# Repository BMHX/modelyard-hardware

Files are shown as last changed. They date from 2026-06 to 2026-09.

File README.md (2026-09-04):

<h1 align="center">Forge 60</h1>

<p align="center">
  <strong>Open-hardware 60 W / 10,000 lm DIY flashlight kit with USB-C power, active cooling, and full manufacturing files.</strong>
</p>

<p align="center">
  
  
  
  
</p>

<p align="center">
  
  
  
</p>

<p align="center">
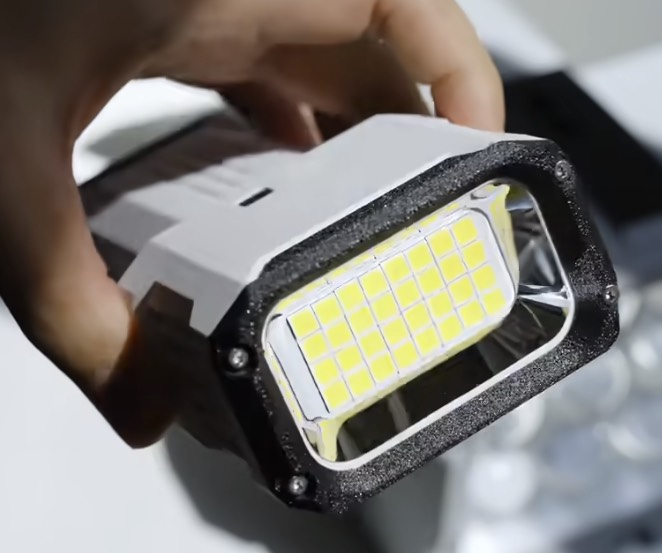
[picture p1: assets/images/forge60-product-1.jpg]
Forge 60 product photo
  
</p>

Forge 60 is a reproducible open-hardware flashlight platform built around a constant 60 W / 10,000 lm output mode, a high-current driver board, a 5050 LED board, active cooling, and a USB-C charge/discharge power path. The repository includes fabrication files, assembly data, schematics, and editable EasyEDA Pro source files so builders can manufacture, inspect, modify, and assemble the project.

## Quick Links

| Action | Link |
| --- | --- |
| YouTube Watch demo | [YouTube video](https://www.youtube.com/watch?v=xSCZzmICGlw) |
| Shopify Buy kit | [ModelYard Forge 60 kit](https://modelyard.cc/products/forge-60) |
| Discord Join community | [Discord invite](https://discord.gg/PhqGwtabfa) |
| GitHub Download release | [GitHub Releases](https://github.com/BMHX/modelyard-hardware/releases) |
| Hardware Download hardware files | [Hardware Downloads](#hardware-downloads) |
| Firmware Download firmware | [Forge 60 OS v1.2 HEX](forge60-hardware-release/firmware/forge60-os-v1.2.hex) |
| Mechanical model Download mechanical model | [Forge 60 v10 3MF](forge60-hardware-release/mechanical/forge60-v10.3mf) |
| Accessory package Download accessory files | [Accessory Package](#accessory-package) |
| Source project Edit source project | [EasyEDA Pro source](forge60-hardware-release/source/forge60-easyeda-pro-source.epro2) |

## At a Glance

| Item | Value |
| --- | --- |
| Output | 60 W / about 10,000 lm |
| USB-C power | About 45 W charging / discharging |
| Battery architecture | 2S 21700 lithium battery pack |
| Cooling | 30 x 30 x 50 mm heatsink + 3010 fan |
| Recommended hardware files | Mainboard v2 + 5050 LED board |
| Mainboard thickness | 1.0 mm |
| LED board thickness | 1.6 mm |
| Firmware | Forge 60 OS v1.2 HEX |
| Mechanical model | Forge 60 v10 3MF |
| Source format | EasyEDA Pro `.epro2` |
| License | CERN-OHL-P-2.0 |

## Important Notes

- **Recommended board:** use `mainboard-v2`. Older mainboard revisions are not recommended for new builds.
- **PCB thickness matters:** order the mainboard at **1.0 mm** and the LED board at **1.6 mm**.
- **LED part:** the 5050 LED board is intended for 6 V 5050 emitters. Current kits use Seoul Semiconductor `STW0L8PA`, 5700 K, around CRI 70. The LED BOM does not use an LCSC part number.
- **KiCad is not included yet:** editable source is currently provided as an EasyEDA Pro project.
- **High-power safety:** this project uses high-current lithium cells and a high-power LED. Validate wiring, polarity, thermal path, and firmware before sustained operation.
- **Battery shipping:** if you ship kits with cells, use a logistics channel that supports lithium batteries.

## Contents

- [Demo](#demo)
- [Kit Availability](#kit-availability)
- [Performance](#performance)
- [Hardware Downloads](#hardware-downloads)
- [Manufacturing Notes](#manufacturing-notes)
- [Firmware and Mechanical Files](#firmware-and-mechanical-files)
- [Accessory Package](#accessory-package)
- [Source Project](#source-project)
- [PCB and Schematic Preview](#pcb-and-schematic-preview)
- [BOM Overview](#bom-overview)
- [Build Flow](#build-flow)
- [Firmware Flashing](#firmware-flashing)
- [Assembly Notes](#assembly-notes)
- [Safety and Disclaimer](#safety-and-disclaimer)
- [Repository Layout](#repository-layout)
- [License](#license)

## Demo

Forge 60 demo video (https://www.youtube.com/watch?v=xSCZzmICGlw)

Watch the demo: [https://www.youtube.com/watch?v=xSCZzmICGlw](https://www.youtube.com/watch?v=xSCZzmICGlw)

## Kit Availability

This repository contains the open hardware files for builders who want to manufacture or modify the project themselves. A ready-to-build kit is available separately:



Direct link: [https://modelyard.cc/products/forge-60](https://modelyard.cc/products/forge-60)

## Performance

| Mode | Runtime |
| --- | --- |
| 60 W | About 27 minutes |
| 30 W | About 54 minutes |
| 3 W | About 8 hours |

These are reference values from the project build. Final performance depends on LED bin, cell condition, protection board, wiring resistance, cooling quality, firmware, and assembly.

## Hardware Downloads

Gerber files are for PCB fabrication. BOM files are for sourcing. Pick-and-place files are for SMT assembly. Schematic and PCB preview files are provided for review.

| Board | Gerber | BOM | Pick and Place | Schematic | PCB Preview |
| --- | --- | --- | --- | --- | --- |
| Mainboard v2 | [ZIP](forge60-hardware-release/mainboard-v2/mainboard-v2-gerber.zip) | [XLSX](forge60-hardware-release/mainboard-v2/mainboard-v2-bom.xlsx) / [CSV](forge60-hardware-release/mainboard-v2/mainboard-v2-bom.csv) | [XLSX](forge60-hardware-release/mainboard-v2/mainboard-v2-pick-and-place.xlsx) / [CSV](forge60-hardware-release/mainboard-v2/mainboard-v2-pick-and-place.csv) | [PDF](forge60-hardware-release/mainboard-v2/mainboard-v2-schematic.pdf) | [PDF](forge60-hardware-release/mainboard-v2/mainboard-v2-pcb-preview.pdf) |
| 5050 LED Board | [ZIP](forge60-hardware-release/led-board-5050/led-board-5050-gerber.zip) | [XLSX](forge60-hardware-release/led-board-5050/led-board-5050-bom.xlsx) / [CSV](forge60-hardware-release/led-board-5050/led-board-5050-bom.csv) | [XLSX](forge60-hardware-release/led-board-5050/led-board-5050-pick-and-place.xlsx) / [CSV](forge60-hardware-release/led-board-5050/led-board-5050-pick-and-place.csv) | [PDF](forge60-hardware-release/led-board-5050/led-board-5050-schematic.pdf) | [PDF](forge60-hardware-release/led-board-5050/led-board-5050-pcb-preview.pdf) |

## Manufacturing Notes

- Mainboard v2: order as **1.0 mm** PCB.
- 5050 LED board: order as **1.6 mm** PCB.
- Use the Gerber zip, BOM, and pick-and-place files from the same board folder.
- The BOM files are the source of truth for electronic components; verify substitutes before assembly.
- If outsourcing SMT, provide the manufacturer with Gerber, BOM, and pick-and-place files together.

## Firmware and Mechanical Files

| File | Link | Use |
| --- | --- | --- |
| Forge 60 OS v1.2 firmware | [forge60-os-v1.2.hex](forge60-hardware-release/firmware/forge60-os-v1.2.hex) | Flash the PY32F003xx6 mainboard MCU |
| Forge 60 v10 mechanical model | [forge60-v10.3mf](forge60-hardware-release/mechanical/forge60-v10.3mf) | 3D-printable mechanical shell/model package |

## Accessory Package

Additional Forge-series accessory files, 3D models, firmware files, stencil files, and source model files are provided at the repository root.

| Folder | Contents |
| --- | --- |
| [Forge60Mecha_Edition](Forge60Mecha_Edition) | Forge 60 Mecha Edition Fusion 360 source, STL package, 3MF package, extended handle STL, and add-on 3MF |
| [Forge65 3D_Files](Forge65%203D_Files) | Forge 65 3MF files, STL package, extended handle 3MF, and 8-cell package |
| [Forge60 65Stencil](Forge60%2065Stencil) | Forge 60 v2 mainboard stencil DXF |
| [Forge200 3D_Models](Forge200%203D_Models) | Forge 200 Fusion 360 source files, STL files, and 3MF files |
| [Forgeos Firmware](Forgeos%20Firmware) | Forge OS firmware HEX files for Forge 60, Forge 65/66, and Forge 201, plus user guide images |
| [Forge500](Forge500) | Forge 500 UF2 firmware files, print files, Fusion 360 source, add-ons, and offline replication document |
| [Forge201 3D_Files](Forge201%203D_Files) | Forge 201 STL package, Fusion 360 source package, 3MF file, and reflective film mold STL |

## Source Project

| Format | Download |
| --- | --- |
| EasyEDA Pro source | [forge60-easyeda-pro-source.epro2](forge60-hardware-release/source/forge60-easyeda-pro-source.epro2) |

The editable project is currently provided in EasyEDA Pro format. KiCad files are not included in this release.

## PCB and Schematic Preview

### PCB Preview

| Mainboard v2 | 5050 LED Board |
| --- | --- |
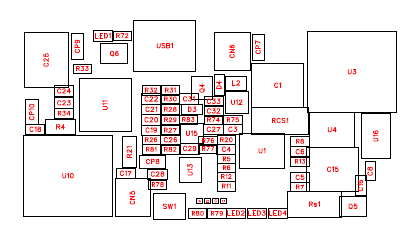
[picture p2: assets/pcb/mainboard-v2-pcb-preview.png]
Mainboard v2 PCB preview
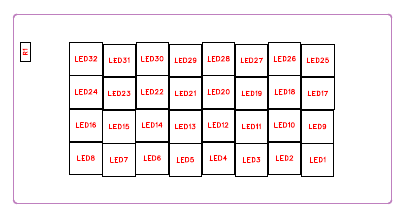
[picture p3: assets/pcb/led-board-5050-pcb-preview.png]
5050 LED board PCB preview
|  |  |

### Schematic Preview

| Mainboard v2 | 5050 LED Board |
| --- | --- |
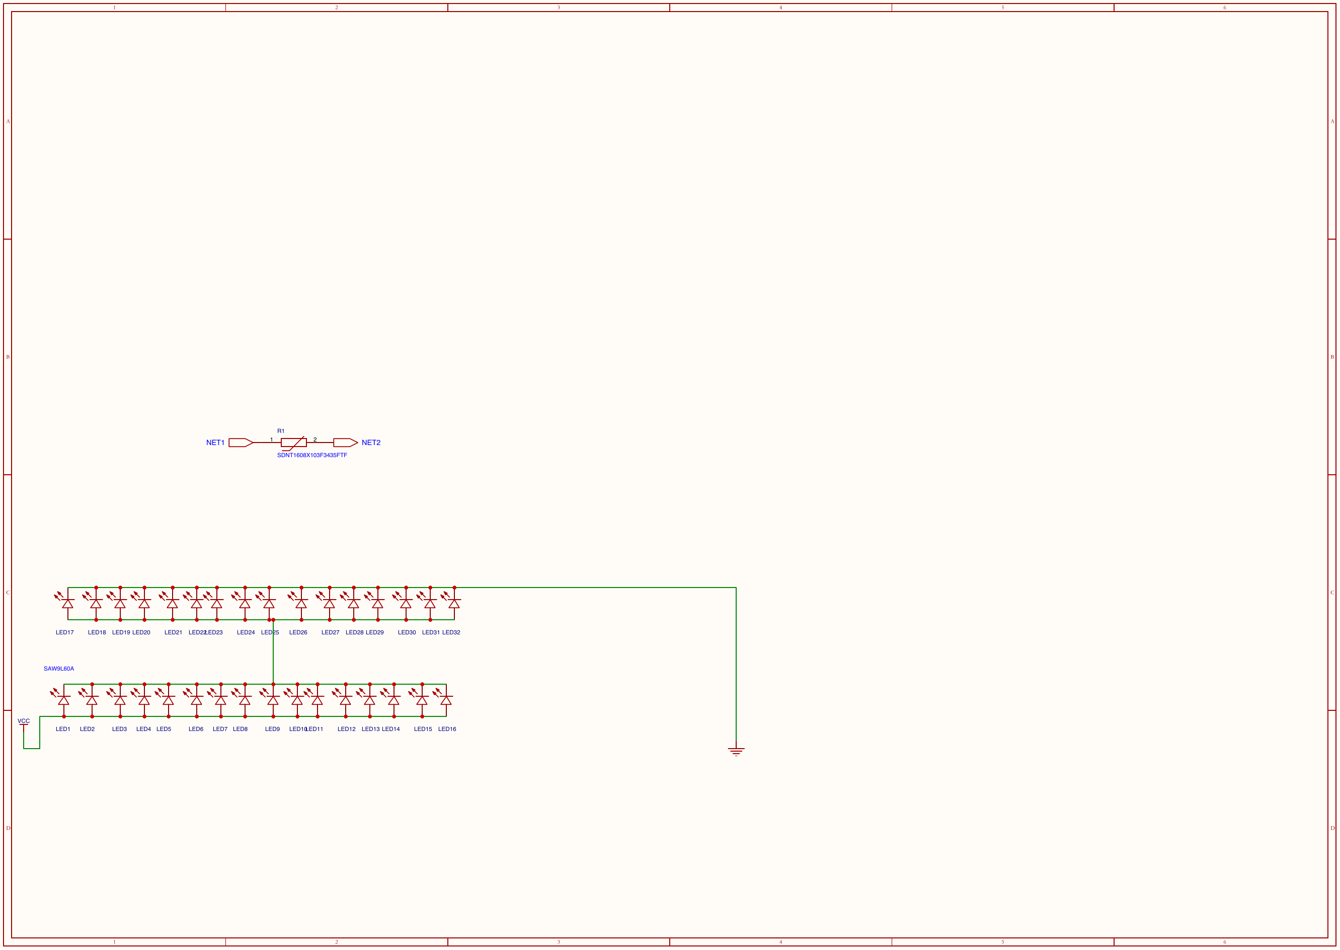
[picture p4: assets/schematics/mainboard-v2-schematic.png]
Mainboard v2 schematic
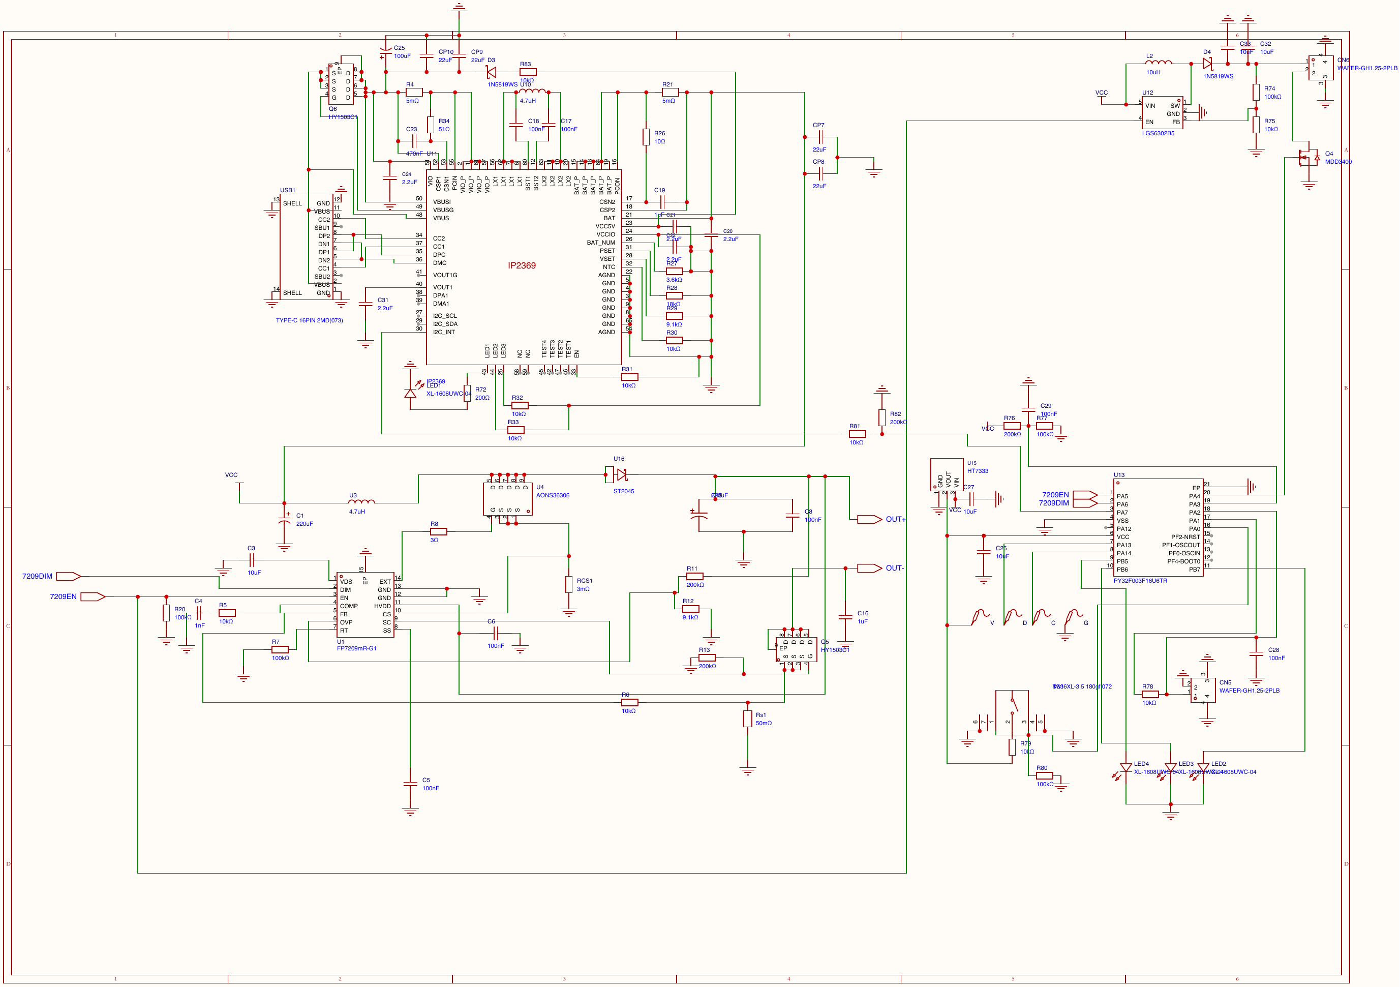
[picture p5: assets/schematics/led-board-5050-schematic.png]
5050 LED board schematic
|  |  |

## BOM Overview

The full BOM is provided in the hardware download table. Major parts include:

- IP2369 charge/discharge controller
- FP7209 LED driver controller
- PY32F003 series MCU
- Seoul Semiconductor STW0L8PA 6 V 5050 LEDs, 5700 K, around CRI 70
- 2S protection board, 13 A class recommended
- High-drain 21700 cells, such as JP40 / 40PL / 45D class cells
- 30 x 30 x 50 mm heatsink
- 3010 cooling fan
- 74 mm protective glass
- XT30 male/female connectors
- GH1.25 2P cables
- 20 AWG and 16 AWG flexible silicone wires
- M1.4 and M1.7 heat-set inserts
- Reflective film, thermal tape, thermal grease, shock-absorbing foam, and high-temperature tape

## Build Flow

1. Review the schematic PDFs and PCB previews.
2. Order the mainboard and LED board using the Gerber files and thickness notes.
3. Source components from the BOM.
4. Use pick-and-place files for SMT assembly where applicable.
5. Print or prepare the mechanical parts and cooling stack.
6. Flash the mainboard firmware.
7. Assemble wiring, LED board, fan, battery pack, and enclosure.
8. Perform current-limited first power-on testing and monitor temperature.

## Required Tools

- 3D printer
- Spot welder
- Hot plate or hot air station
- Soldering iron
- PWLINK2 LITE programmer
- 1.25 mm programming probe
- Glass cutter, if cutting the protective glass manually
- H1.3 / H1.5 hex drivers

## Firmware Flashing

Use PWLINK2 LITE and select the PY32F003xx6 series target in the programming software. Pay close attention to the V and G pads on the mainboard. Reversed programming probe wiring can damage the board.

| Select MCU | Add firmware | Apply firmware |
| --- | --- | --- |
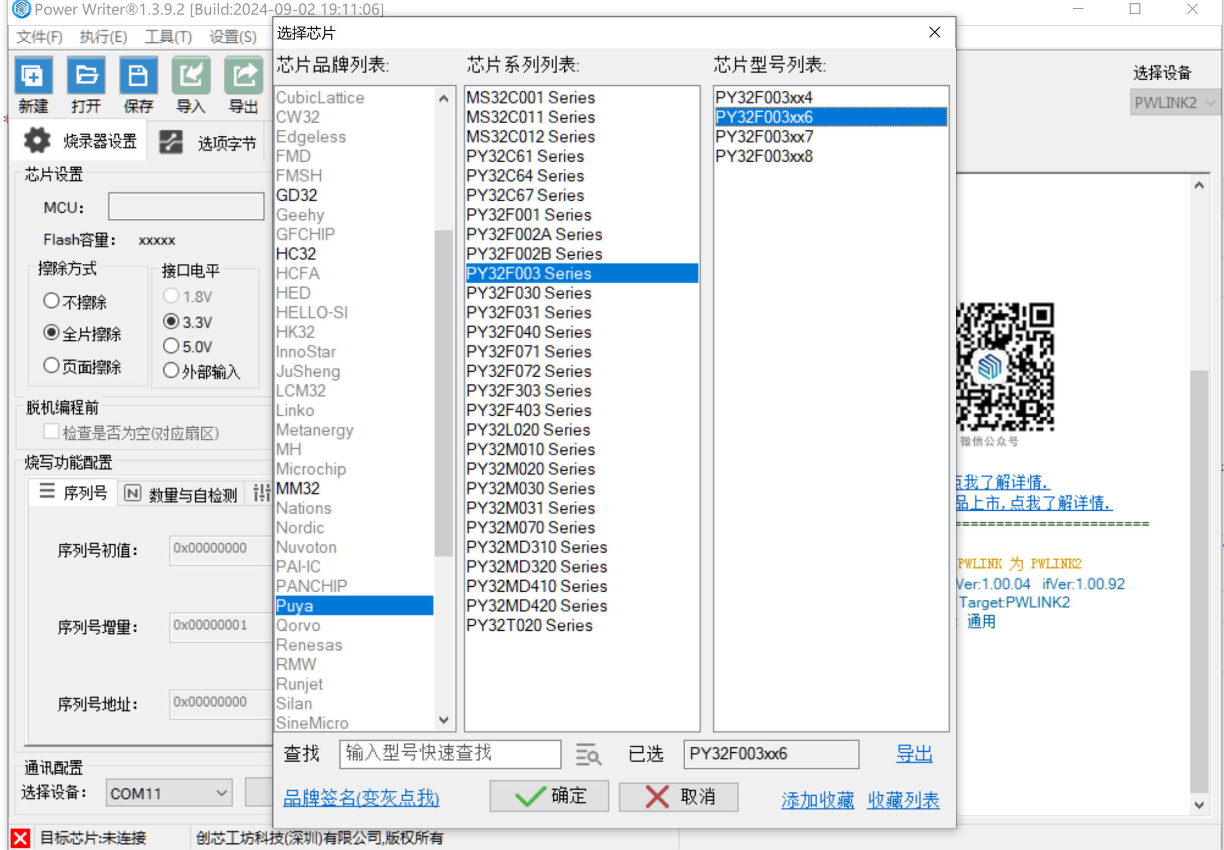
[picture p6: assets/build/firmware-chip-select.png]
Select chip
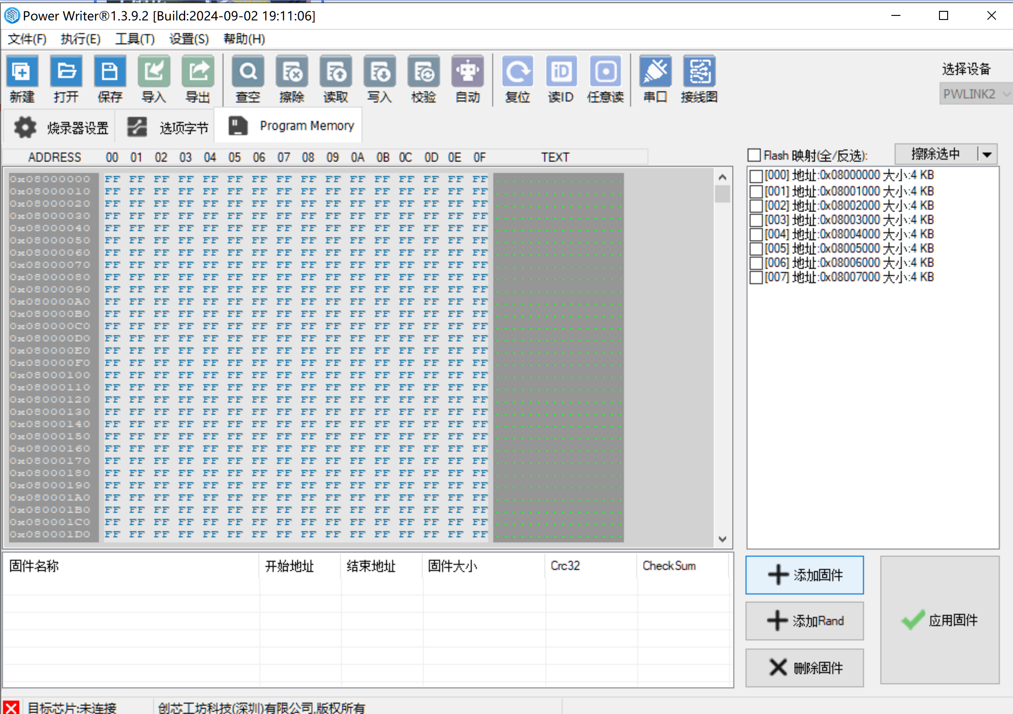
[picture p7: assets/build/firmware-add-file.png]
Add firmware
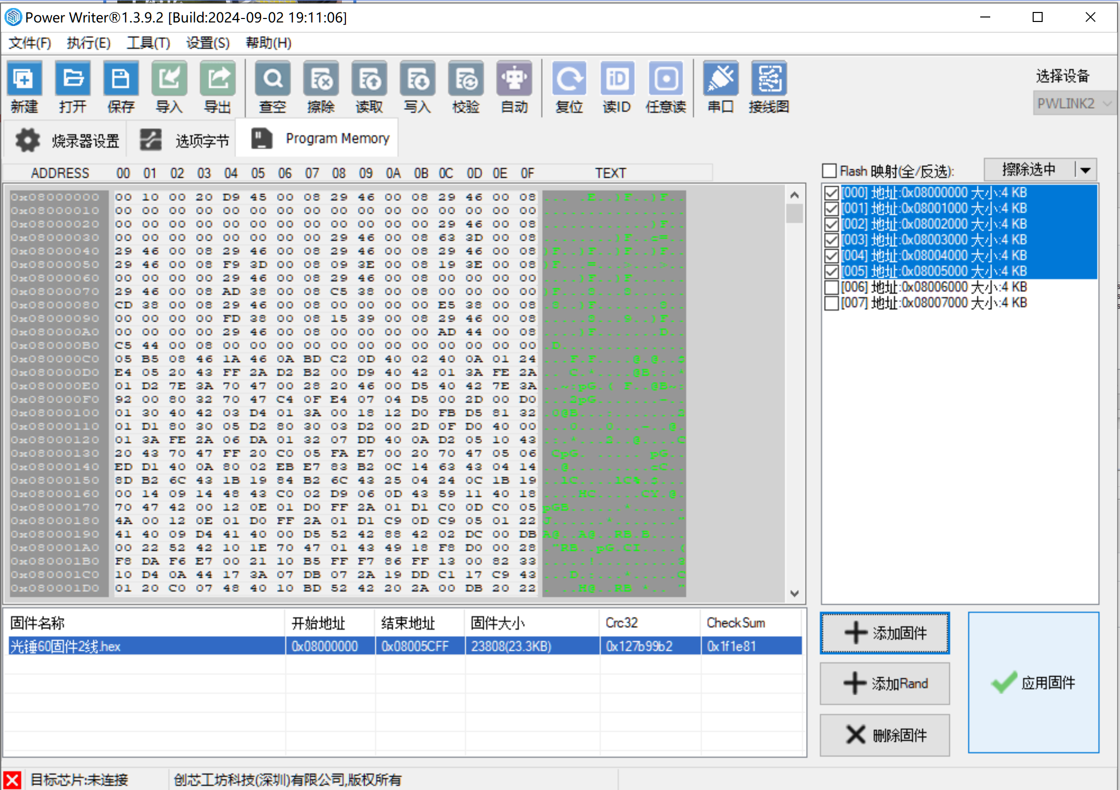
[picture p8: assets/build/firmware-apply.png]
Apply firmware
|  |  |  |

| Probe wiring | Mainboard pads | Program complete |
| --- | --- | --- |
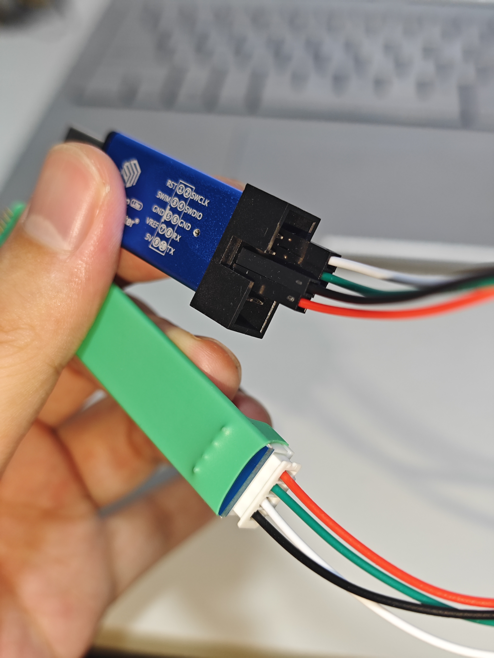
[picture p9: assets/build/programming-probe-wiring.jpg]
Programming probe wiring
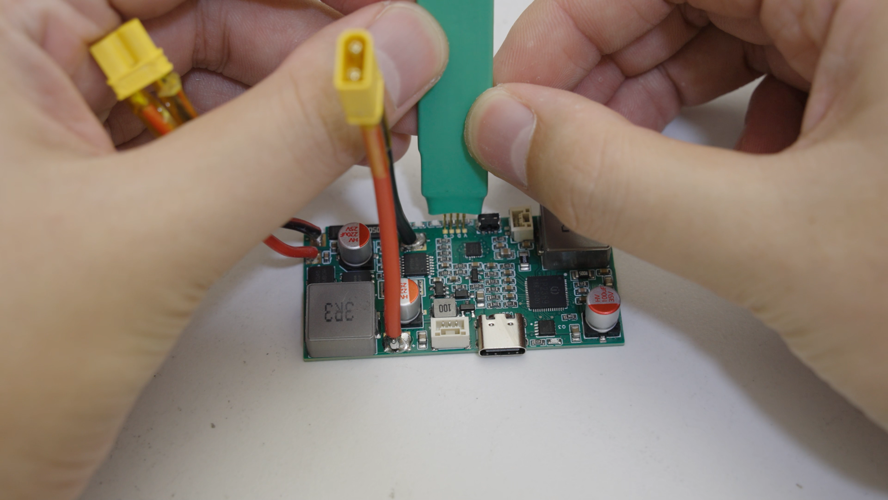
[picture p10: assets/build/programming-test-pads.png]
Programming probe pads
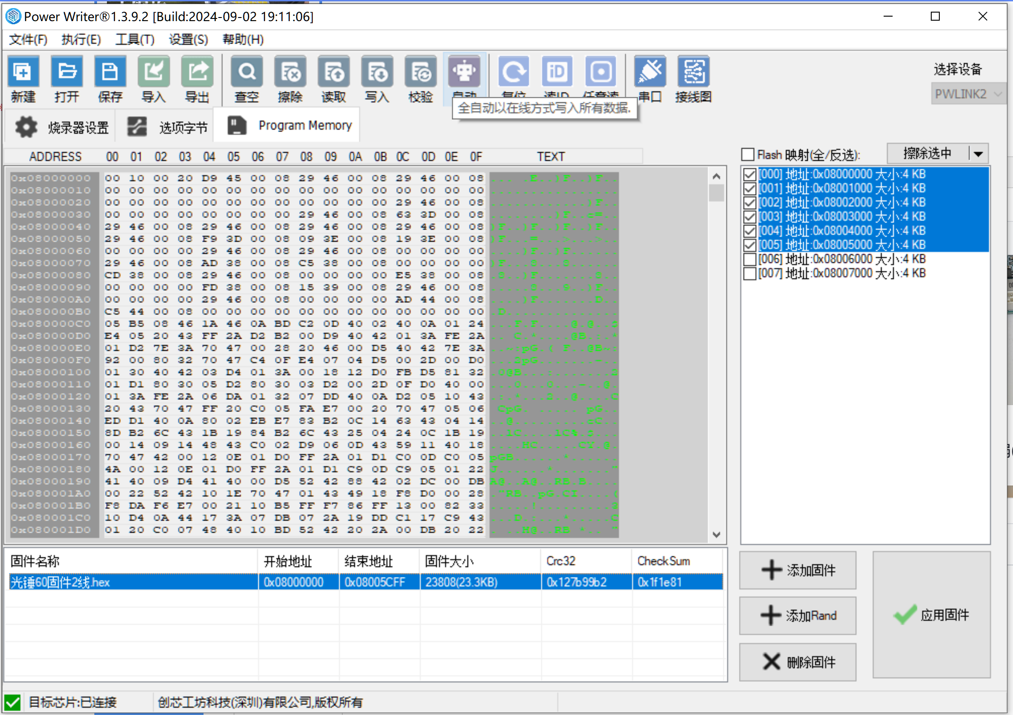
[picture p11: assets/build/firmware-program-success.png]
Firmware program success
|  |  |  |

## Assembly Notes

1. Flash the mainboard firmware before final assembly.
2. Use 16 AWG silicone wire for the mainboard input and XT30 male connector.
3. Use 20 AWG silicone wire and GH1.25 2P cables on the LED board side.
4. Mount the 3010 fan to the heatsink, then modify the fan lead to GH1.25 2P if needed.
5. Connect the mainboard output, LED board input, temperature sensing line, and fan line before closing the structure.
6. Use M1.7 heat-set inserts for the lamp-head top cover and M1.4 heat-set inserts for the handle connection.
7. Center the protection board inside the handle battery pack.
8. Add foam around the battery pack output side to reduce vibration and compression risk.

| Mainboard input wiring | Fan installation | Fan connector modification |
| --- | --- | --- |
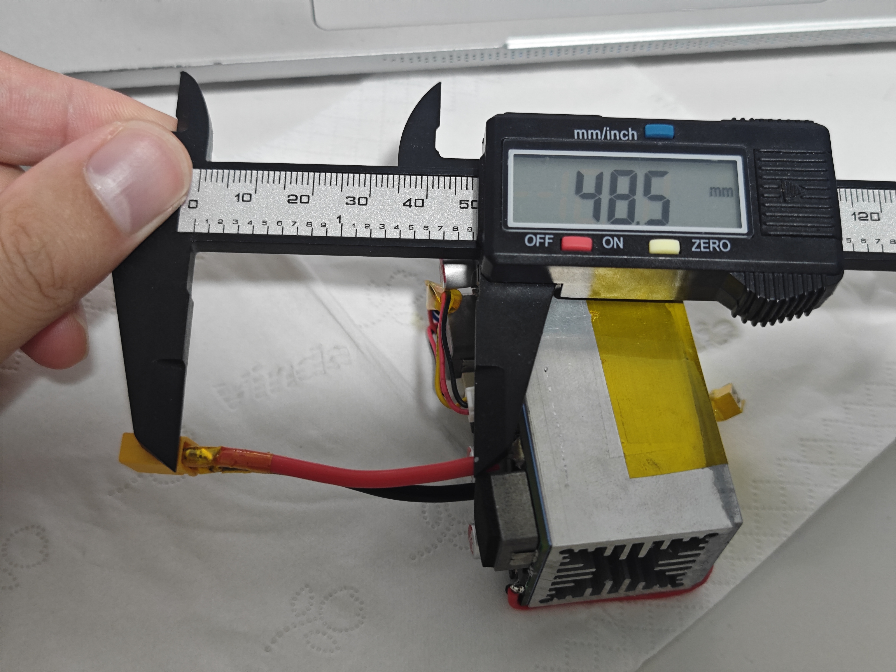
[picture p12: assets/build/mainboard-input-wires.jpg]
Mainboard input wires
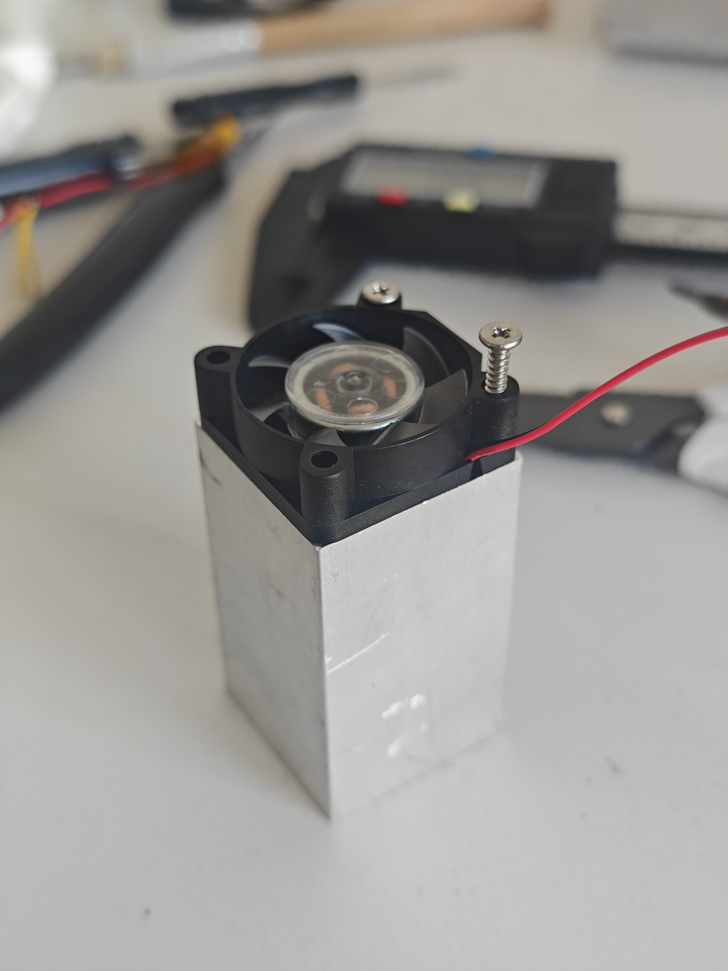
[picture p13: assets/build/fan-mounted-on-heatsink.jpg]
Fan mounted on heatsink
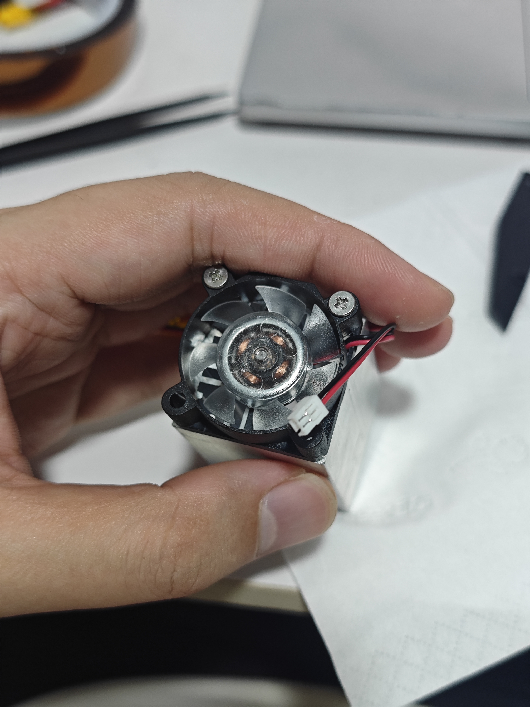
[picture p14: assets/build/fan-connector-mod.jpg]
Fan connector modification
|  |  |  |

| Mainboard and LED board wiring | Battery pack installation |
| --- | --- |
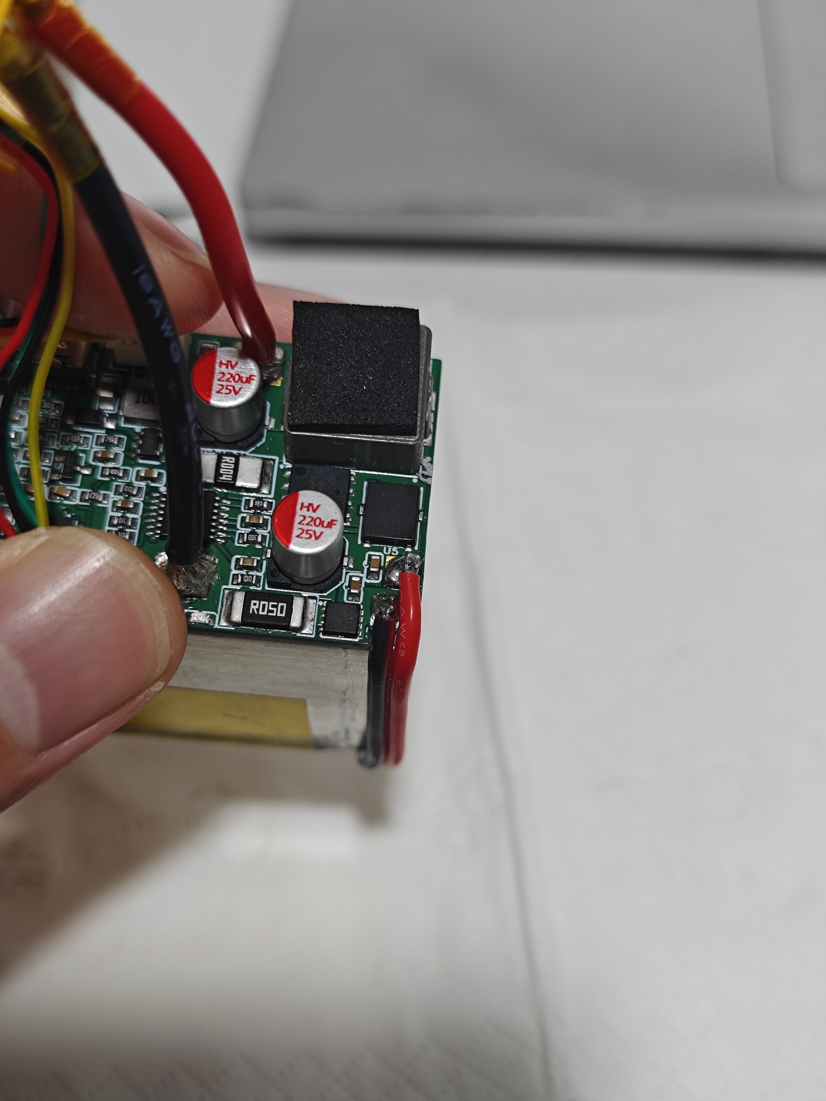
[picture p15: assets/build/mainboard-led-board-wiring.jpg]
Mainboard and LED board wiring
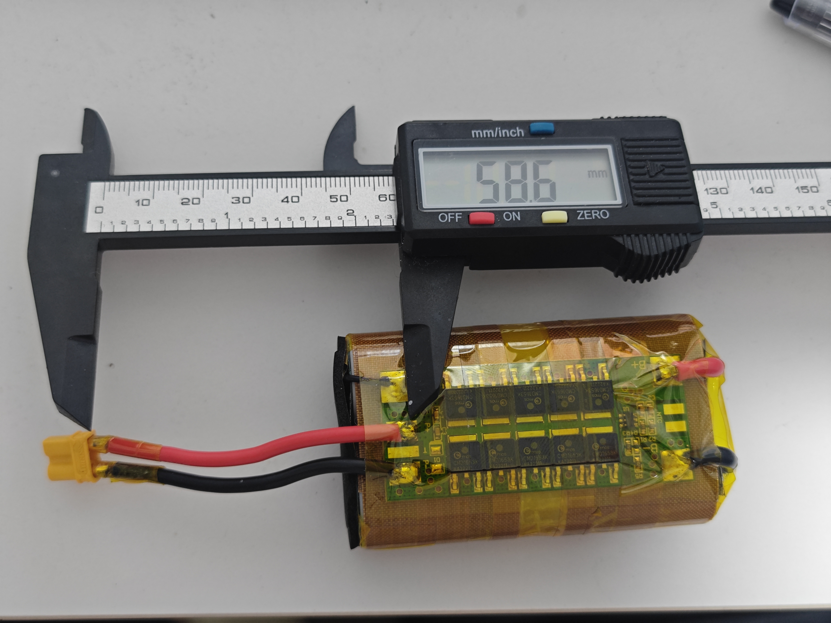
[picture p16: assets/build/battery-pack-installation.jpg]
Battery pack installation
|  |  |

## Operation

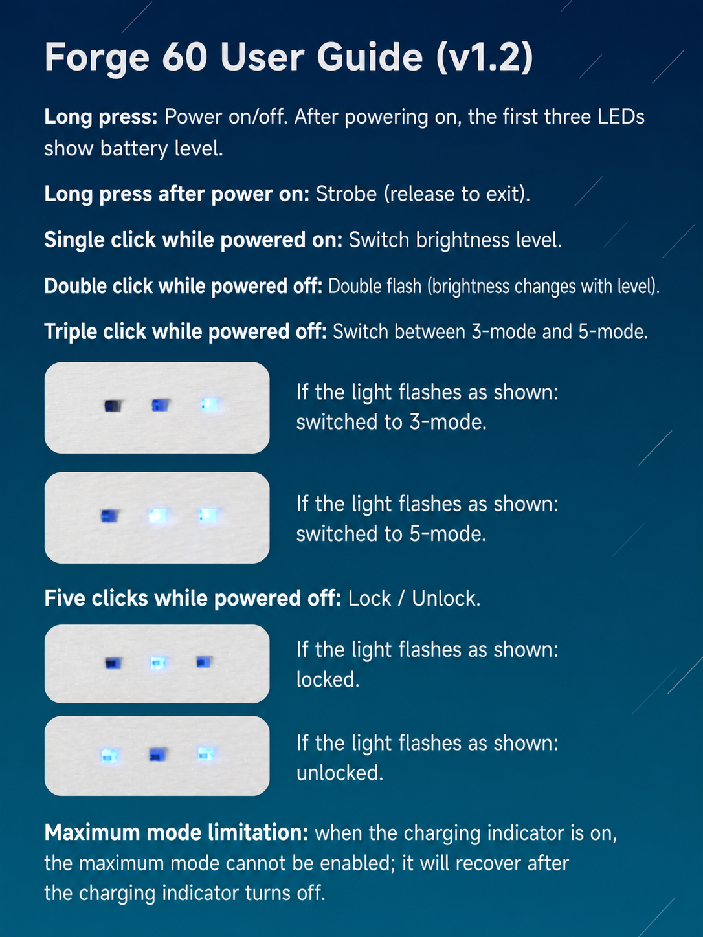
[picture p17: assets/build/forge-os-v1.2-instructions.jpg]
Forge OS v1.2 instructions


## Community

For build discussion, support, updates, and modification ideas:



Direct link: [https://discord.gg/PhqGwtabfa](https://discord.gg/PhqGwtabfa)

## Safety and Disclaimer

This is a high-power LED and lithium battery project. Build and test it carefully.

- Do not downgrade protection board, cell, wire, or connector specifications.
- Verify the thermal path before sustained high-power operation.
- Check polarity and programming probe orientation before flashing.
- Current-limit the first power-on test and monitor temperature.
- Do not leave the battery pack or high-power LED unattended during early testing.
- If shipping batteries internationally, use a logistics channel that supports lithium batteries.
- You are responsible for validating the design, assembly, firmware, battery pack, and thermal behavior before use.

## Repository Layout

```text
forge60-hardware-release/
  firmware/
    forge60-os-v1.2.hex
  mainboard-v2/
    mainboard-v2-gerber.zip
    mainboard-v2-bom.xlsx
    mainboard-v2-bom.csv
    mainboard-v2-pick-and-place.xlsx
    mainboard-v2-pick-and-place.csv
    mainboard-v2-schematic.pdf
    mainboard-v2-pcb-preview.pdf
  led-board-5050/
    led-board-5050-gerber.zip
    led-board-5050-bom.xlsx
    led-board-5050-bom.csv
    led-board-5050-pick-and-place.xlsx
    led-board-5050-pick-and-place.csv
    led-board-5050-schematic.pdf
    led-board-5050-pcb-preview.pdf
  mechanical/
    forge60-v10.3mf
  source/
    forge60-easyeda-pro-source.epro2

Forge60Mecha_Edition/
Forge65 3D_Files/
Forge60 65Stencil/
Forge200 3D_Models/
Forgeos Firmware/
Forge500/
Forge201 3D_Files/
```

## License

This hardware project is released under the CERN Open Hardware Licence Version 2 - Permissive (`CERN-OHL-P-2.0`). Commercial use is allowed under the terms of the license.

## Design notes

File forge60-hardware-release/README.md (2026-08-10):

# Forge 60 Release

<p>
  
  
  
  
</p>

Forge 60 is a compact high-power DIY flashlight project built around a 60 W class driver, a 5050 LED board, USB-C charging/discharging, active cooling, and a 2S 21700 battery pack.

This release packages the files needed to reproduce the electronics, flash the controller firmware, and print the mechanical shell.

## Release Metadata

| Item | Value |
| --- | --- |
| Release package | `forge60-hardware-release-v1.0.0.zip` |
| Hardware release | v1.0.0 |
| Mainboard | `mainboard-v2` |
| Firmware | Forge 60 OS v1.2 |
| Mechanical model | Forge 60 v10 |
| Source format | EasyEDA Pro |

## Download Release

| Package | Link | Use |
| --- | --- | --- |
| Full release ZIP | [GitHub Releases](https://github.com/BMHX/modelyard-hardware/releases/download/v1.0.0/forge60-hardware-release-v1.0.0.zip) | Download the complete hardware, firmware, and mechanical package |
| Release page | [Forge 60 v1.0.0](https://github.com/BMHX/modelyard-hardware/releases/tag/v1.0.0) | View release notes and attached assets |

## What Is Included

| Area | Folder | Contents |
| --- | --- | --- |
| Main control board | `mainboard-v2/` | Gerber, BOM, pick-and-place, schematic, PCB preview |
| 5050 LED board | `led-board-5050/` | Gerber, BOM, pick-and-place, schematic, PCB preview |
| Firmware | `firmware/` | Forge 60 OS firmware HEX |
| Mechanical model | `mechanical/` | 3D-printable 3MF model |
| Source project | `source/` | EasyEDA Pro source project |

## Recommended Order

1. Read the [safety notes](#safety).
2. Review the schematic and PCB preview PDFs in [Board Files](#board-files).
3. Order PCBs using the matching Gerber files.
4. Source parts from the matching BOM files.
5. Use the pick-and-place files for SMT assembly.
6. Print the [3MF mechanical model](#mechanical-model) and verify fitment.
7. Flash the [firmware](#firmware) before final assembly.

## Board Files

### Mainboard v2

| File | Link |
| --- | --- |
| Gerber | [mainboard-v2-gerber.zip](mainboard-v2/mainboard-v2-gerber.zip) |
| BOM | [XLSX](mainboard-v2/mainboard-v2-bom.xlsx) / [CSV](mainboard-v2/mainboard-v2-bom.csv) |
| Pick and place | [XLSX](mainboard-v2/mainboard-v2-pick-and-place.xlsx) / [CSV](mainboard-v2/mainboard-v2-pick-and-place.csv) |
| Schematic | [mainboard-v2-schematic.pdf](mainboard-v2/mainboard-v2-schematic.pdf) |
| PCB preview | [mainboard-v2-pcb-preview.pdf](mainboard-v2/mainboard-v2-pcb-preview.pdf) |

### 5050 LED Board

| File | Link |
| --- | --- |
| Gerber | [led-board-5050-gerber.zip](led-board-5050/led-board-5050-gerber.zip) |
| BOM | [XLSX](led-board-5050/led-board-5050-bom.xlsx) / [CSV](led-board-5050/led-board-5050-bom.csv) |
| Pick and place | [XLSX](led-board-5050/led-board-5050-pick-and-place.xlsx) / [CSV](led-board-5050/led-board-5050-pick-and-place.csv) |
| Schematic | [led-board-5050-schematic.pdf](led-board-5050/led-board-5050-schematic.pdf) |
| PCB preview | [led-board-5050-pcb-preview.pdf](led-board-5050/led-board-5050-pcb-preview.pdf) |

## Manufacturing Notes

| Item | Recommended setting |
| --- | --- |
| Mainboard version | `mainboard-v2` |
| Mainboard thickness | 1.0 mm |
| Mainboard layer count | 4 layers |
| LED board thickness | 1.6 mm |
| LED board package | 5050 LED layout |
| LED part | Seoul Semiconductor `STW0L8PA`, 6 V 5050, 5700 K, around CRI 70 |
| Assembly files | Use the matching BOM and pick-and-place files from the same board folder |

Before ordering, review the PCB preview PDF and confirm board stack-up, substrate, copper weight, surface finish, and assembly constraints with the PCB manufacturer.

The LED board BOM intentionally leaves the LED supplier part number blank because the current kit LED is not an LCSC part. Do not substitute the LED row with an 0805 indicator LED.

## Firmware

- Firmware file: [firmware/forge60-os-v1.2.hex](firmware/forge60-os-v1.2.hex)
- Target MCU family: PY32F003xx6
- Recommended programmer: PWLINK2 LITE

Check the programming probe orientation before flashing. Reversed V/G wiring can damage the mainboard.

## Mechanical Model

- 3MF model: [mechanical/forge60-v10.3mf](mechanical/forge60-v10.3mf)

Verify fitment against your printed material, printer tolerance, heat-set insert size, fan, heatsink, wiring length, and battery pack before final assembly.

## Source Project

- EasyEDA Pro source: [source/forge60-easyeda-pro-source.epro2](source/forge60-easyeda-pro-source.epro2)

Use the source project when you need to inspect or modify the schematic, PCB layout, BOM, or fabrication outputs.

## Repository Layout

```text
forge60-hardware-release/
  firmware/
    forge60-os-v1.2.hex
  led-board-5050/
    led-board-5050-bom.csv
    led-board-5050-bom.xlsx
    led-board-5050-gerber.zip
    led-board-5050-pcb-preview.pdf
    led-board-5050-pick-and-place.csv
    led-board-5050-pick-and-place.xlsx
    led-board-5050-schematic.pdf
  mainboard-v2/
    mainboard-v2-bom.csv
    mainboard-v2-bom.xlsx
    mainboard-v2-gerber.zip
    mainboard-v2-pcb-preview.pdf
    mainboard-v2-pick-and-place.csv
    mainboard-v2-pick-and-place.xlsx
    mainboard-v2-schematic.pdf
  mechanical/
    forge60-v10.3mf
  source/
    forge60-easyeda-pro-source.epro2
```

## Safety

This is a high-power LED and lithium battery project. Use current-limited first power-on testing, verify polarity, monitor temperature, and do not downgrade the battery, protection board, wire, connector, or cooling specifications.

## License

This hardware project is released under the CERN Open Hardware Licence Version 2 - Permissive (`CERN-OHL-P-2.0`). Commercial use is allowed under the terms of the license.

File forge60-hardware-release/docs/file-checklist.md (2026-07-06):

# File Checklist

## Firmware

- `firmware/forge60-os-v1.2.hex`

## Mainboard v2

- `mainboard-v2/mainboard-v2-gerber.zip`
- `mainboard-v2/mainboard-v2-bom.xlsx`
- `mainboard-v2/mainboard-v2-bom.csv`
- `mainboard-v2/mainboard-v2-pick-and-place.xlsx`
- `mainboard-v2/mainboard-v2-pick-and-place.csv`
- `mainboard-v2/mainboard-v2-schematic.pdf`
- `mainboard-v2/mainboard-v2-pcb-preview.pdf`

## 5050 LED Board

- `led-board-5050/led-board-5050-gerber.zip`
- `led-board-5050/led-board-5050-bom.xlsx`
- `led-board-5050/led-board-5050-bom.csv`
- `led-board-5050/led-board-5050-pick-and-place.xlsx`
- `led-board-5050/led-board-5050-pick-and-place.csv`
- `led-board-5050/led-board-5050-schematic.pdf`
- `led-board-5050/led-board-5050-pcb-preview.pdf`

## Mechanical Model

- `mechanical/forge60-v10.3mf`

## Source

- `source/forge60-easyeda-pro-source.epro2`

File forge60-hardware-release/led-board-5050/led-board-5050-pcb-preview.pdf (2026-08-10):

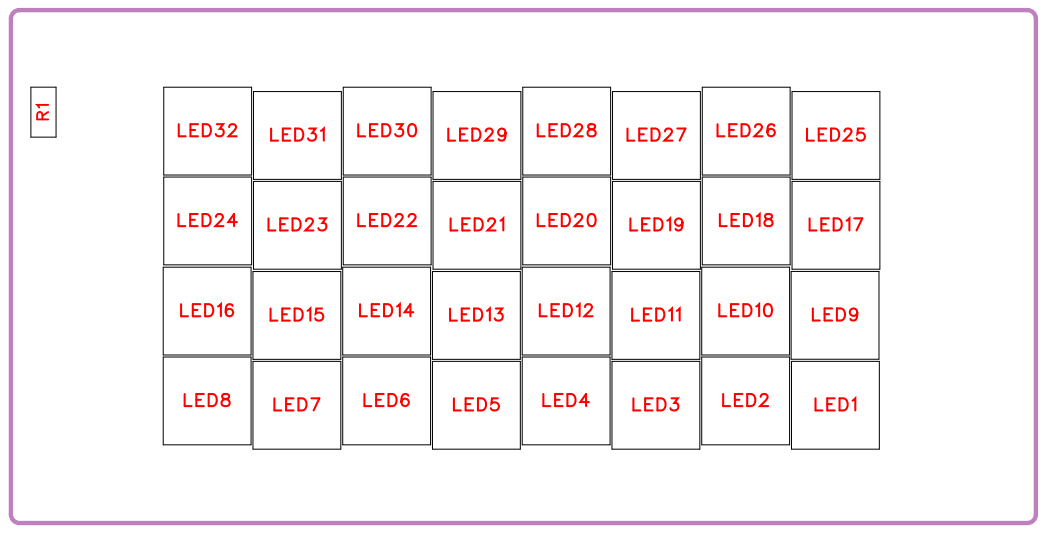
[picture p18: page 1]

LED32 | LED31 | LED30 | LED29 | LED28 | LED27 | LED26 | LED25

LED24 | LED23 | LED22 | LED21 | LED20 | LED19 | LED18 | LED17

LED16 | LED15 | LED14 | LED13 | LED12 | LED11 | LED10 | LED9

LED8 | LED7 | LED6 | LED5 | LED4 | LED3 | LED2 | LED1

No. | Quantity | Comment | Designator | Footprint | Value | Manufacturer Part | Manufacturer | Supplier Part | Supplier
1 | 32 | STW0L8PA | LED1,LED2,LED3,LED4,LE D5,LED6,LED7,LED8,LED9 ,LED10,LED11,LED12,LED 13,LED14,LED15,LED16,LE D17,LED18,LED19,LED20, LED21,LED22,LED23,LED2 4,LED25,LED26,LED27,LE D28,LED29,LED30,LED31, LED32 | emc5050-1 | | STW0L8PA | Seoul | | LCSC
2 | 1 | SDNT1608X 103F3435FT F | R1 | R0603 | | SDNT1608X 103F3435FT F | Sunlord(顺络 ) | C525660 | LCSC

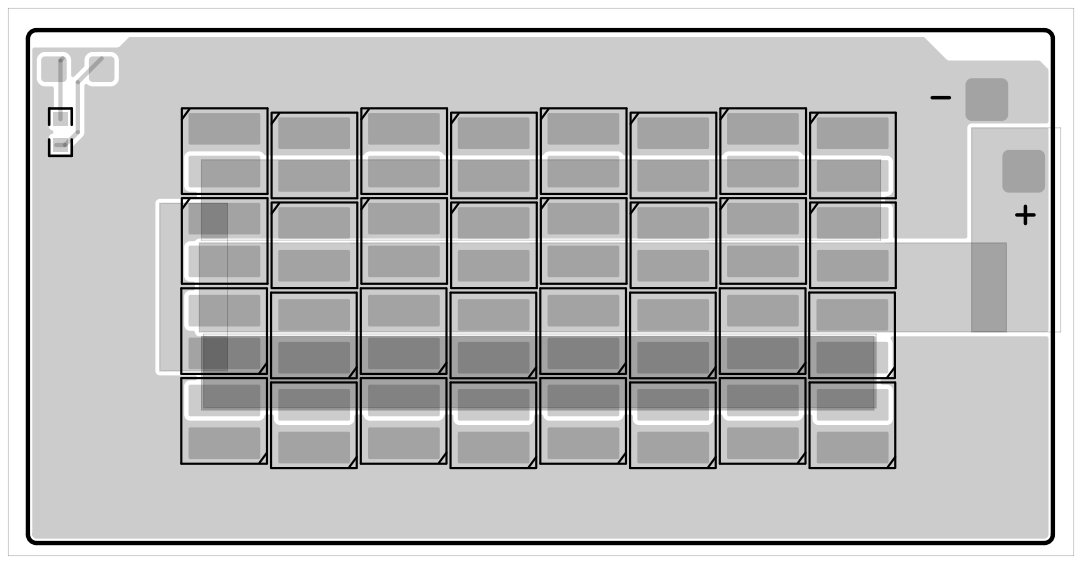
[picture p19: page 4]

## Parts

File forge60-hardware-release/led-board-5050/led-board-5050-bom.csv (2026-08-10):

No. | Quantity | Comment | Designator | Footprint | Value | Manufacturer Part | Manufacturer | Supplier Part | Supplier
1 | 32 | STW0L8PA | LED1,LED2,LED3,LED4,LED5,LED6,LED7,LED8,LED9,LED10,LED11,LED12,LED13,LED14,LED15,LED16,LED17,LED18,LED19,LED20,LED21,LED22,LED23,LED24,LED25,LED26,LED27,LED28,LED29,LED30,LED31,LED32 | emc5050-1 | 6V 5050 white LED, 5700K, CRI 70 | STW0L8PA | Seoul Semiconductor
2 | 1 | SDNT1608X103F3435FTF | R1 | R0603 |  | SDNT1608X103F3435FTF | Sunlord(顺络) | C525660 | LCSC

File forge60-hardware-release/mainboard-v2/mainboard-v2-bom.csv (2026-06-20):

No. | Quantity | Comment | Designator | Footprint | Value | Manufacturer Part | Manufacturer | Supplier Part | Supplier
1 | 2 | 220uF | C1,C15 | CAP-SMD_BD6.3-L6.6-W6.6-LS7.0-FD | 220uF | HV1E227M0607PZ | HONOR(荣誉) | C5246541 | LCSC
2 | 5 | 10uF | C3,C26,C27,C32,C33 | C0603 | 10uF | CL10A106MA8NRNC | SAMSUNG(三星) | C96446 | LCSC
3 | 1 | 1nF | C4 | C0603 | 1nF | CC0603KRX7R0BB102 | YAGEO(国巨) | C106247 | LCSC
4 | 7 | 100nF | C5,C6,C8,C17,C18,C28,C29 | C0603 | 100nF | 0603B104K101NT | FH(风华) | C88219 | LCSC
5 | 2 | 1uF | C16,C19 | C0603 | 1uF | 0603B105K500NT | FH(风华) | C90540 | LCSC
6 | 5 | 2.2uF | C20,C21,C22,C24,C31 | C0603 | 2.2uF | CL10A225KB8NNNC | SAMSUNG(三星) | C913904 | LCSC
7 | 1 | 470nF | C23 | C0603 | 470nF | CL10B474KA8NNNC | SAMSUNG(三星) | C1623 | LCSC
8 | 1 | 100uF | C25 | CAP-SMD_BD6.3-L6.5-W6.5-LS7.2-FD | 100uF | KNM2100UF35V149EC0055 | KNSCHA(科尼盛) | C2982822 | LCSC
9 | 4 | Test-Point | C,D,G,V | Test-Point-0.5mm
10 | 2 | WAFER-GH1.25-2PLB | CN5,CN6 | CONN-TH_2P-P1.25_XUNPU_WAFER-GH1.25-2PLB |  | WAFER-GH1.25-2PLB | XUNPU(讯普) | C3029368 | LCSC
11 | 4 | 22uF | CP7,CP8,CP9,CP10 | C0805 | 22uF | CL21A226MAYNNNE | SAMSUNG(三星) | C602037 | LCSC
12 | 2 | 1N5819WS | D3,D4 | SOD-323_L1.8-W1.3-LS2.5-RD |  | 1N5819WS | Hottech(合科泰) | C191023 | LCSC
13 | 1 | 10uH | L2 | IND-SMD_L2.5-W2.0 | 10uH | FTC252012S100MBCA | cjiang(长江微电) | C5832376 | LCSC
14 | 4 | XL-1608UWC-04 | LED1,LED2,LED3,LED4 | LED0603-RD_WHITE |  | XL-1608UWC-04 | XINGLIGHT(成兴光) | c434421 | LCSC
15 | 1 | MDD3400 | Q4 | SOT-23-3_L2.9-W1.5-P1.90-LS2.6-BR |  | MDD3400 | MDD(辰达半导体) | C427382 | LCSC
16 | 2 | HY1503C1 | Q5,Q6 | DFN-8_L3.0-W3.0-P0.65-BL_VBQFXXXX |  | HY1503C1 | HUAYI(华羿微) | C358109 | LCSC
17 | 2 | 5mΩ | R4,R21 | R1206 | 5mΩ | FMF06FTHR005-LH | PSA(信昌电陶) | C464975 | LCSC
18 | 11 | 10kΩ | R5,R6,R30,R31,R32,R33,R75,R78,R79,R81,R83 | R0603 | 10kΩ | 0603WAF1002T5E | UNI-ROYAL(厚声) | C25804 | LCSC
19 | 5 | 100kΩ | R7,R20,R74,R77,R80 | R0603 | 100kΩ | 0603WAF1003T5E | UNI-ROYAL(厚声) | C25803 | LCSC
20 | 1 | 3Ω | R8 | R0603 | 3Ω | RC0603FR-073RL | YAGEO(国巨) | C137724 | LCSC
21 | 4 | 200kΩ | R11,R13,R76,R82 | R0603 | 200kΩ | 0603WAF2003T5E | UNI-ROYAL(厚声) | C25811 | LCSC
22 | 2 | 9.1kΩ | R12,R29 | R0603 | 9.1kΩ | 0603WAF9101T5E | UNI-ROYAL(厚声) | C23260 | LCSC
23 | 1 | 10Ω | R26 | R0603 | 10Ω | 0603WAF100JT5E | UNI-ROYAL(厚声) | C22859 | LCSC
24 | 1 | 3.6kΩ | R27 | R0603 | 3.6kΩ | 0603WAF3601T5E | UNI-ROYAL(厚声) | C22980 | LCSC
25 | 1 | 18kΩ | R28 | R0603 | 18kΩ | 0603WAF1802T5E | UNI-ROYAL(厚声) | C25810 | LCSC
26 | 1 | 51Ω | R34 | R0603 | 51Ω | 0603WAF510JT5E | UNI-ROYAL(厚声) | C23197 | LCSC
27 | 1 | 200Ω | R72 | R0603 | 200Ω | 0603WAF2000T5E | UNI-ROYAL(厚声) | C8218 | LCSC
28 | 1 | 3mΩ | RCS1 | RES-SMD_L6.4-W3.2-A | 3mΩ | LRBN25GFER003S | NCT(利昇达) | C5121073 | LCSC
29 | 1 | 50mΩ | Rs1 | RES-SMD_L6.4-W3.2-R2512 | 50mΩ | HoJLR2512-3W-50mR-1% | Milliohm(毫欧) | C2903475 | LCSC
30 | 1 | TS36XL-3.5 180gf 072 | SW1 | SW-TH_SHOU-HAN_TS36XL-3.5 |  | TS36XL-3.5 180gf 072 | SHOU HAN(首韩) | C2859426 | LCSC
31 | 1 | FP7209mR-G1 | U1 | TSSOP-14_L5.0-W4.4-P0.65-LS6.4-BL-EP |  | FP7209mR-G1 | Advanced Analog Technology(类比) | C2762848 | LCSC
32 | 2 | 4.7uH | U3,U10 | IND-SMD_L13.5-W12.8 | 4.7uH | CXP1250-4R7M-HG(4.7uh) | DMBJ(振宝佳) | C5273816 | LCSC
33 | 1 | AONS36306 | U4 | PG-TDSON-8_L5.9-W5.2-P1.27-LS6.2-BL-EP |  | AONS36306 | AOS | C3277800 | LCSC
34 | 1 | IP2369 | U11 | QFN-7*7-60-5
35 | 1 | LGS6302B5 | U12 | SOT-23-5_L3.0-W1.6-P0.95-LS2.8-BL |  | LGS6302B5 | Legend-Si(棱晶半导体) | C5123975 | LCSC
36 | 1 | PY32F003F16U6TR | U13 | QFN-20_L3.0-W3.0-P0.40-BL-EP1.7 |  | PY32F003F16U6TR | PUYA(普冉) | C3018714 | LCSC
37 | 1 | HT7333 | U15 | SOT-23-3_L2.9-W1.6-P1.90-LS2.8-BR |  | HT7333 | 国芯佳品 | C2684634 | LCSC
38 | 1 | ST2045 | U16 | TO-277_3P-L5.4-W4.0-LS6.5-BR |  | ST2045 | HXY MOSFET(华轩阳电子) | C20611945 | LCSC
39 | 1 | TYPE-C 16PIN 2MD(073) | USB1 | USB-C-SMD_TYPE-C-6PIN-2MD-073 |  | TYPE-C 16PIN 2MD(073) | SHOU HAN(首韩) | C2765186 | LCSC

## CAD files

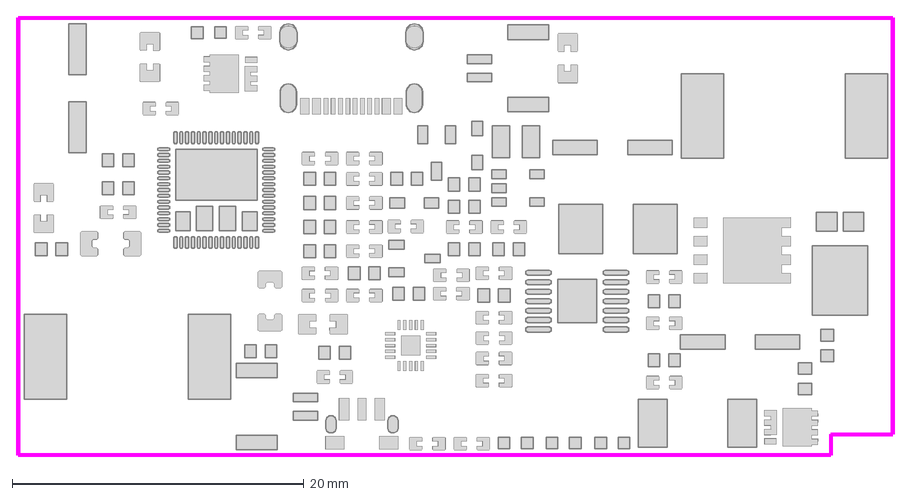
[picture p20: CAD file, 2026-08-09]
Forge60 65Stencil/Forge60v2MainboardStencil.dxf
60.3 x 30.3 mm

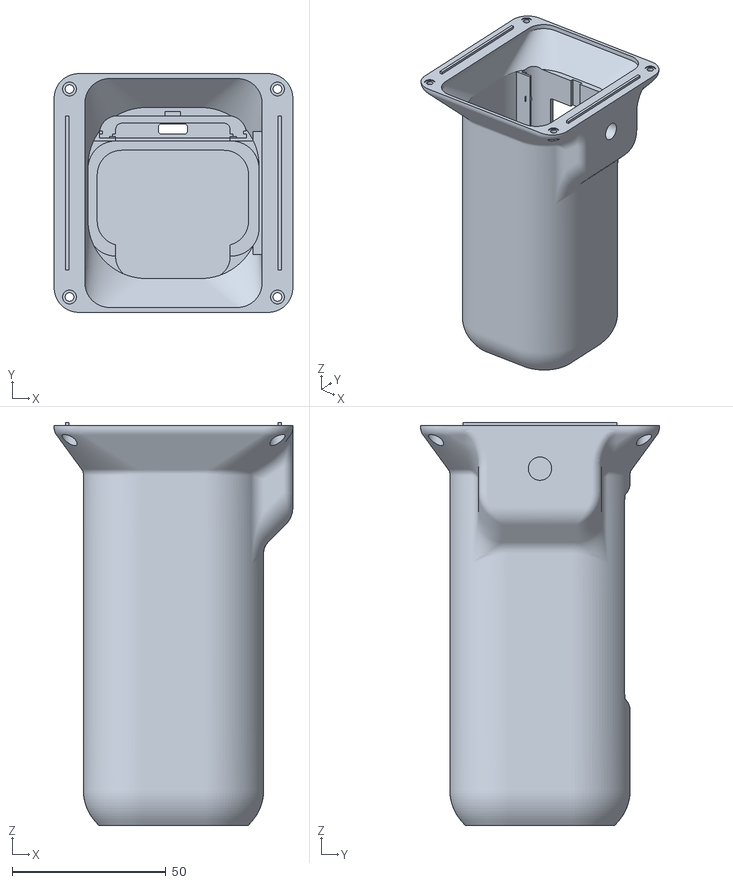
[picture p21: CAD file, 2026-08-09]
Forge200 3D_Models/Forge200Handle.stl
77.6 x 77.6 x 131.0

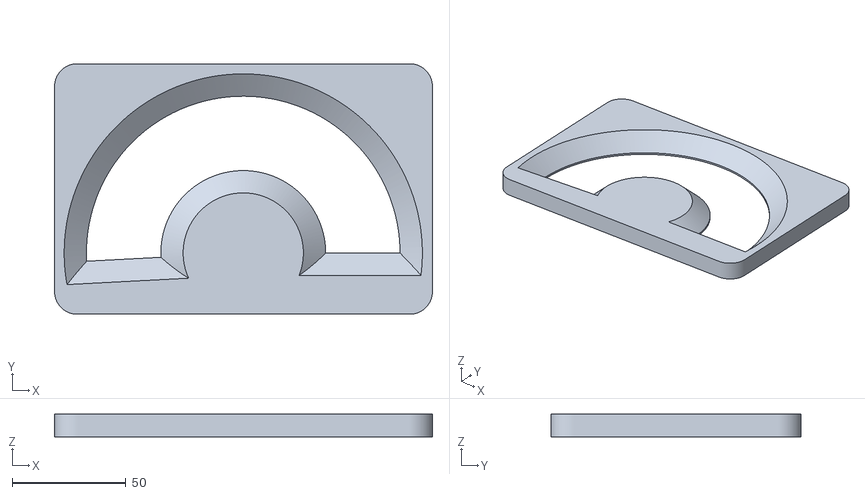
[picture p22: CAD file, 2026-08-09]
Forge201 3D_Files/Forge201 Reflective_Film_Mold.stl
166.0 x 110.0 x 10.0

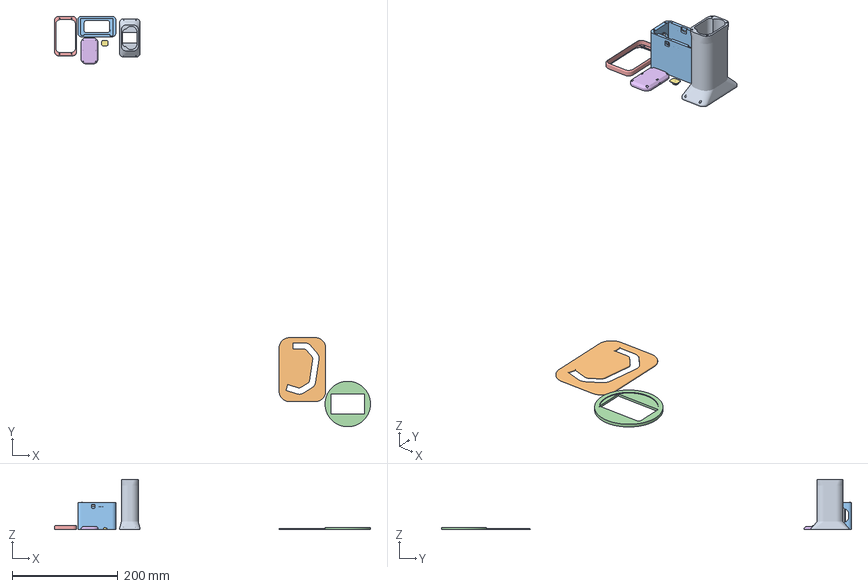
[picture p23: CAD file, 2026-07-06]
forge60-hardware-release/mechanical/forge60-v10.3mf
597.6 x 776.2 x 95.2 mm
光锤66手柄.stl
反光模具.stl
光锤60灯筒v8.stl
玻璃切割模具.stl
光锤60顶盖v7.stl
光锤60尾盖v3.stl
光锤65按钮.stl

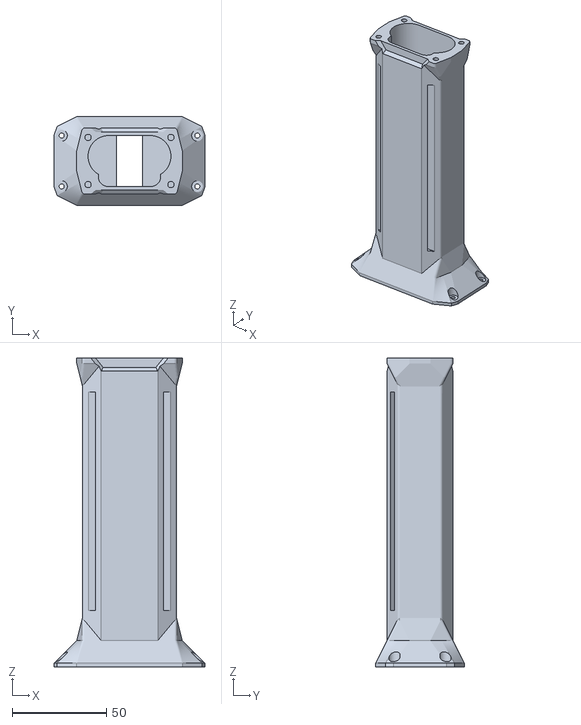
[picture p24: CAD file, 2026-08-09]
Forge60Mecha_Edition/60Mecha_EditionHandle Extended70mm.stl
80.0 x 47.0 x 164.0

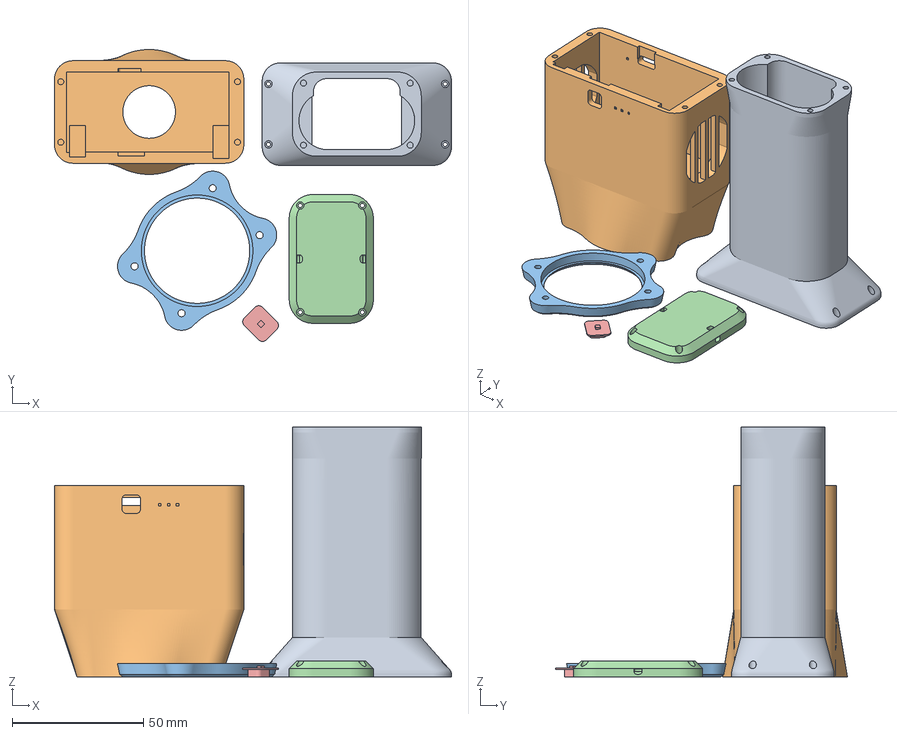
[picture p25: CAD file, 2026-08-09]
Forge65 3D_Files/Forge65v1.3mf
151.0 x 111.0 x 95.0 mm
光锤65手柄.stl
光锤65灯头.stl
光锤65顶盖.stl
光锤60尾盖v3.stl
光锤65按钮.stl

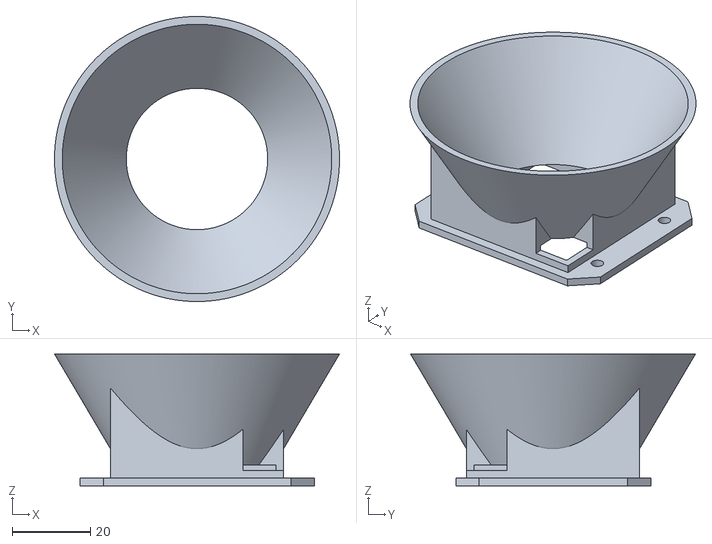
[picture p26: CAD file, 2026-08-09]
Forge200 3D_Models/Forge200Reflector.stl
73.0 x 73.0 x 33.8

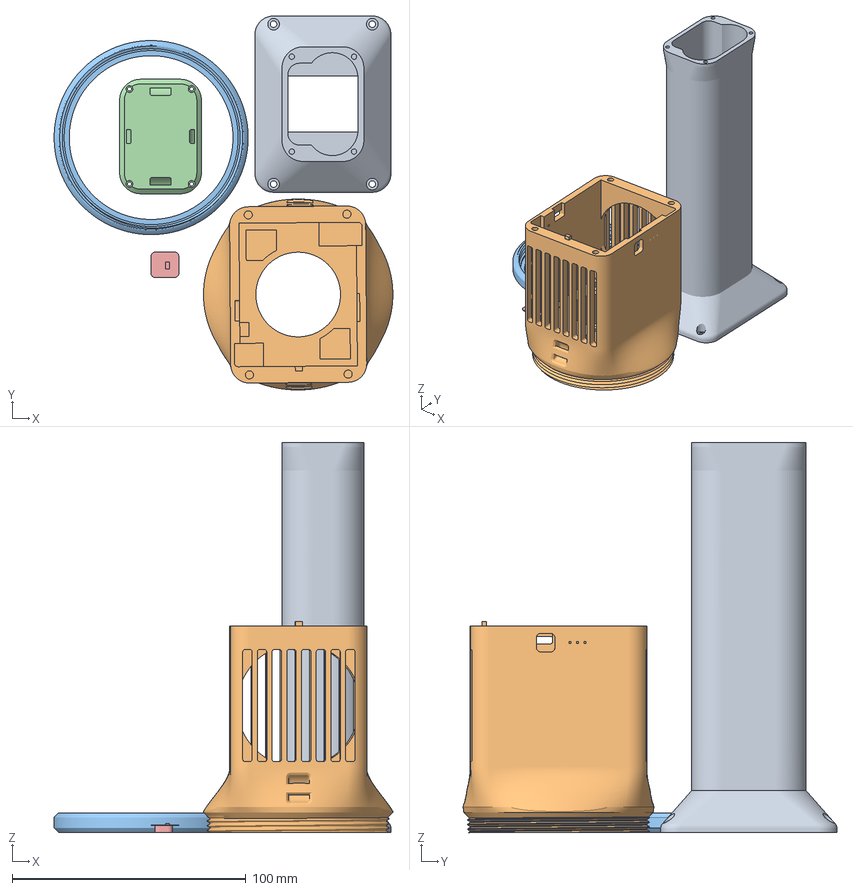
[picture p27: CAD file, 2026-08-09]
Forge201 3D_Files/Forge201 v1.0.3mf
144.9 x 160.0 x 167.0 mm
光锤201 手柄.stl
光锤201 灯头.stl
光锤201 顶盖.stl
光锤201 尾盖.stl
光锤201 按钮.stl

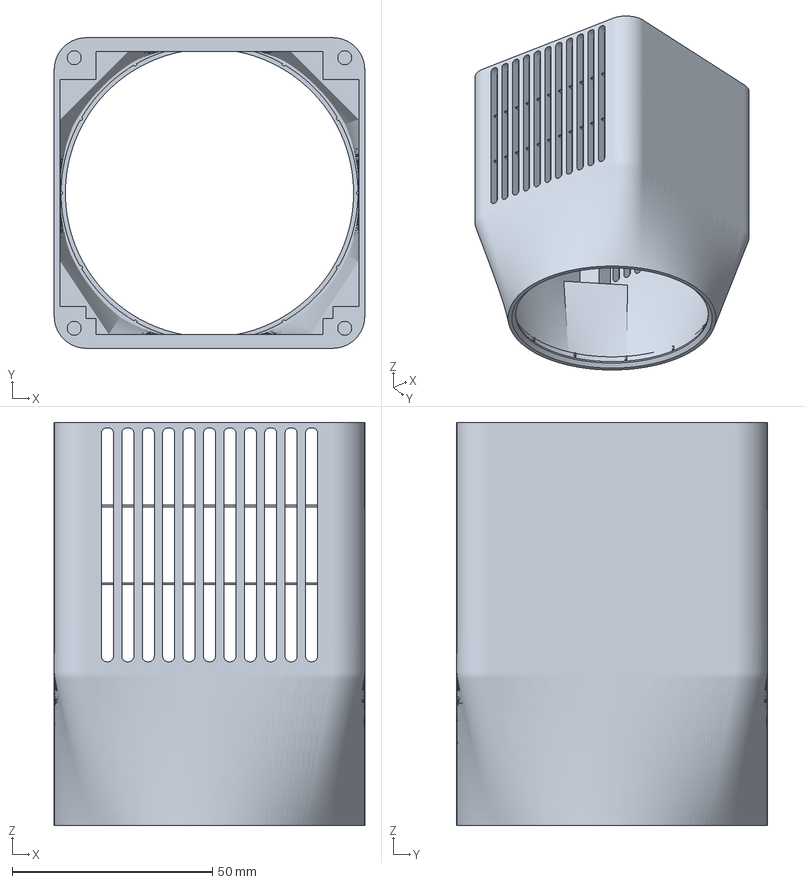
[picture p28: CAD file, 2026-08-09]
Forge200 3D_Models/Lamp_Body_Heat_Press.3mf
77.6 x 77.6 x 100.7 mm

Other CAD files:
Forge60Mecha_Edition/Add-ons/Forge60v10.3mf
Forge65 3D_Files/Forge65v1HandleExtended.3mf
Forge200 3D_Models/Photography_Handle.3mf
Forge200 3D_Models/Forge200Lamp_Body.stl
Forge200 3D_Models/Flashlightv3 v32.f3d
Forge200 3D_Models/HandlePhotography_Light_Version v3.f3d
Forge200 3D_Models/ledClipv2 v12.f3d
Forge500/500EnclosureFusion360_Source.f3z
Forge60Mecha_Edition/Forge60Mecha_Edition.f3d

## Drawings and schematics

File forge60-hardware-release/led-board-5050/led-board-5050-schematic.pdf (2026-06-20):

# GND 65 BAT_P ⁶⁴

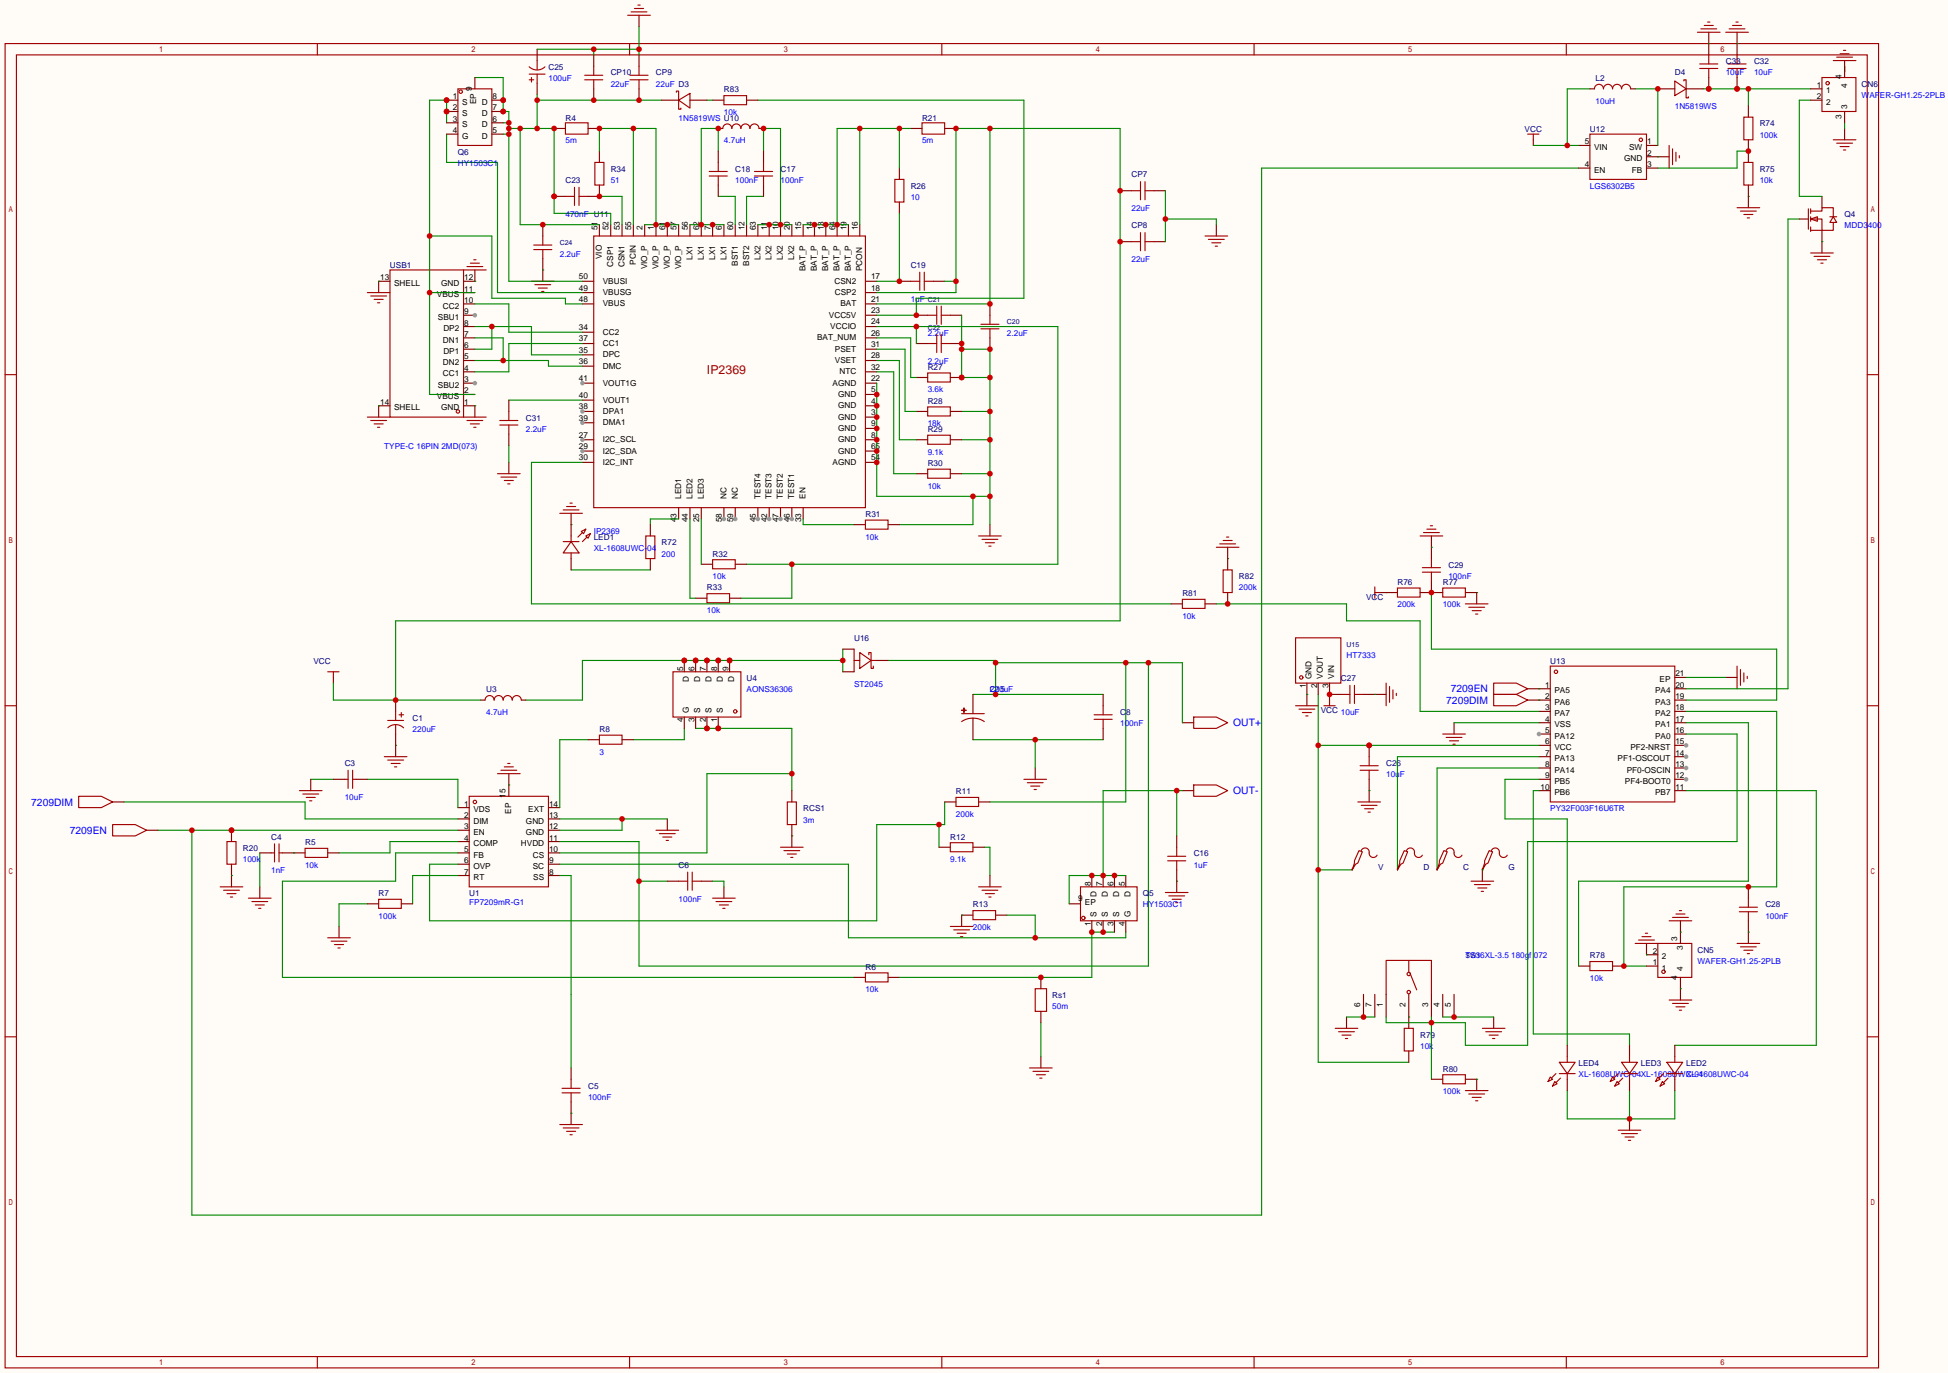
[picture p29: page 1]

CS 10 HVDD 11 GND 12 GND 13 EXT 14

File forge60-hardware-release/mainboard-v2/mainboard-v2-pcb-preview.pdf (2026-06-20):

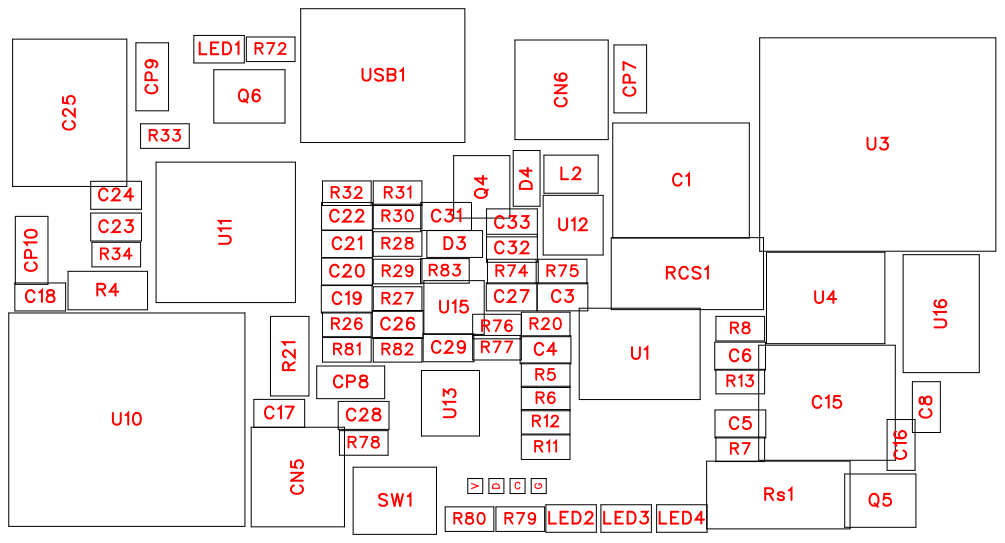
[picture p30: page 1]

R81 | R82 | C29 | R77 | C4 | C6
CP8 | | | | R5 | R13

R78 | | R11 | | R7
SW1 | C G | Rs1 | Q5
R80 | R79 | LED2 LED3 LED4

No. | Quantity | Comment | Designator | Footprint | Value | Manufacturer Part | Manufacturer | Supplier Part | Supplier
1 | 2 | 220uF | C1,C15 | CAP-SMD_B D6.3-L6.6-W 6.6-LS7.0-FD | 220uF | HV1E227M0 607PZ | HONOR(荣誉 ) | C5246541 | LCSC
2 | 5 | 10uF | C3,C26,C27,C32,C33 | C0603 | 10uF | CL10A106M A8NRNC | SAMSUNG( 三星) | C96446 | LCSC
3 | 1 | 1nF | C4 | C0603 | 1nF | CC0603KRX 7R0BB102 | YAGEO(国巨 ) | C106247 | LCSC
4 | 7 | 100nF | C5,C6,C8,C17,C18,C28,C2 9 | C0603 | 100nF | 0603B104K1 01NT | FH(风华) | C88219 | LCSC
5 | 2 | 1uF | C16,C19 | C0603 | 1uF | 0603B105K5 00NT | FH(风华) | C90540 | LCSC
6 | 5 | 2.2uF | C20,C21,C22,C24,C31 | C0603 | 2.2uF | CL10A225KB 8NNNC | SAMSUNG( 三星) | C913904 | LCSC
7 | 1 | 470nF | C23 | C0603 | 470nF | CL10B474KA 8NNNC | SAMSUNG( 三星) | C1623 | LCSC
8 | 1 | 100uF | C25 | CAP-SMD_B D6.3-L6.5-W 6.5-LS7.2-FD | 100uF | KNM2100UF 35V149EC00 55 | KNSCHA(科 尼盛) | C2982822 | LCSC
9 | 4 | Test-Point | C,D,G,V | Test-Point-0. 5mm
10 | 2 | WAFER-GH1 .25-2PLB | CN5,CN6 | CONN-TH_2 P-P1.25_XU NPU_WAFE R-GH1.25-2P LB | | WAFER-GH1 .25-2PLB | XUNPU(讯普 ) | C3029368 | LCSC
11 | 4 | 22uF | CP7,CP8,CP9,CP10 | C0805 | 22uF | CL21A226M AYNNNE | SAMSUNG( 三星) | C602037 | LCSC
12 | 2 | 1N5819WS | D3,D4 | SOD-323_L1 .8-W1.3-LS2. 5-RD | | 1N5819WS | Hottech(合科 泰) | C191023 | LCSC
13 | 1 | 10uH | L2 | IND-SMD_L2 .5-W2.0 | 10uH | FTC252012S 100MBCA | cjiang(长江微 电) | C5832376 | LCSC
14 | 4 | XL-1608UW C-04 | LED1,LED2,LED3,LED4 | LED0603-RD _WHITE | | XL-1608UW C-04 | XINGLIGHT( 成兴光) | c434421 | LCSC
15 | 1 | MDD3400 | Q4 | SOT-23-3_L2 .9-W1.5-P1.9 0-LS2.6-BR | | MDD3400 | MDD(辰达半 导体) | C427382 | LCSC
16 | 2 | HY1503C1 | Q5,Q6 | DFN-8_L3.0-W3.0-P0.65-BL_VBQFXX XX | | HY1503C1 | HUAYI(华羿 微) | C358109 | LCSC
17 | 2 | 5m | R4,R21 | R1206 | 5m | FMF06FTHR 005-LH | PSA(信昌电 陶) | C464975 | LCSC
18 | 11 | 10k | R5,R6,R30,R31,R32,R33,R 75,R78,R79,R81,R83 | R0603 | 10k | 0603WAF10 02T5E | UNI-ROYAL( 厚声) | C25804 | LCSC
19 | 5 | 100k | R7,R20,R74,R77,R80 | R0603 | 100k | 0603WAF10 03T5E | UNI-ROYAL( 厚声) | C25803 | LCSC

20 | 1 | 3 | R8 | R0603 | 3 | RC0603FR-0 73RL | YAGEO(国巨 ) | C137724 | LCSC
21 | 4 | 200k | R11,R13,R76,R82 | R0603 | 200k | 0603WAF20 03T5E | UNI-ROYAL( ) 厚声 | C25811 | LCSC
22 | 2 | 9.1k | R12,R29 | R0603 | 9.1k | 0603WAF91 01T5E | UNI-ROYAL( ) 厚声 | C23260 | LCSC
23 | 1 | 10 | R26 | R0603 | 10 | 0603WAF10 0JT5E | UNI-ROYAL( 厚声 ) | C22859 | LCSC
24 | 1 | 3.6k | R27 | R0603 | 3.6k | 0603WAF36 01T5E | UNI-ROYAL( 厚声 ) | C22980 | LCSC
25 | 1 | 18k | R28 | R0603 | 18k | 0603WAF18 02T5E | UNI-ROYAL( 厚声 ) | C25810 | LCSC
26 | 1 | 51 | R34 | R0603 | 51 | 0603WAF51 0JT5E | UNI-ROYAL( ) 厚声 | C23197 | LCSC
27 | 1 | 200 | R72 | R0603 | 200 | 0603WAF20 00T5E | UNI-ROYAL( ) 厚声 | C8218 | LCSC
28 | 1 | 3m | RCS1 | RES-SMD_L 6.4-W3.2-A | 3m | LRBN25GFE R003S | NCT(利昇达 ) | C5121073 | LCSC
29 | 1 | 50m | Rs1 | RES-SMD_L 6.4-W3.2-R2 512 | 50m | HoJLR2512-3W-50mR-1 % | Milliohm(毫欧 ) | C2903475 | LCSC
30 | 1 | TS36XL-3.5 180gf 072 | SW1 | SW-TH_SHO U-HAN_TS3 6XL-3.5 | | TS36XL-3.5 180gf 072 | SHOU HAN(首韩 ) | C2859426 | LCSC
31 | 1 | FP7209mR-G1 | U1 | TSSOP-14_L 5.0-W4.4-P0. 65-LS6.4-BL-EP | | FP7209mR-G1 | Advanced Analog Tech nology(类比 ) | C2762848 | LCSC
32 | 2 | 4.7uH | U3,U10 | IND-SMD_L1 3.5-W12.8 | 4.7uH | CXP1250-4R 7M-HG(4.7uh ) | DMBJ(振宝佳 ) | C5273816 | LCSC
33 | 1 | AONS36306 | U4 | PG-TDSON-8_L5.9-W5.2-P1.27-LS6.2-BL-EP | | AONS36306 | AOS | C3277800 | LCSC
34 | 1 | IP2369 | U11 | QFN-7*7-60- 5
35 | 1 | LGS6302B5 | U12 | SOT-23-5_L3 .0-W1.6-P0.9 5-LS2.8-BL | | LGS6302B5 | Legend-Si( 棱 ) 晶半导体 | C5123975 | LCSC
36 | 1 | PY32F003F1 6U6TR | U13 | QFN-20_L3.0 -W3.0-P0.40-BL-EP1.7 | | PY32F003F1 6U6TR | PUYA(普冉 ) | C3018714 | LCSC
37 | 1 | HT7333 | U15 | SOT-23-3_L2 .9-W1.6-P1.9 0-LS2.8-BR | | HT7333 | 国芯佳品 | C2684634 | LCSC
38 | 1 | ST2045 | U16 | TO-277_3P-L 5.4-W4.0-LS 6.5-BR | | ST2045 | HXY MOSFE T(华轩阳电子 ) | C20611945 | LCSC

39

1 | TYPE-C
16PIN
2MD(073)
USB1 | USB-C-SMD
_TYPE-C-6PI
N-2MD-073

TYPE-C
16PIN
2MD(073)

SHOU
HAN(首韩

)

C2765186 LCSC

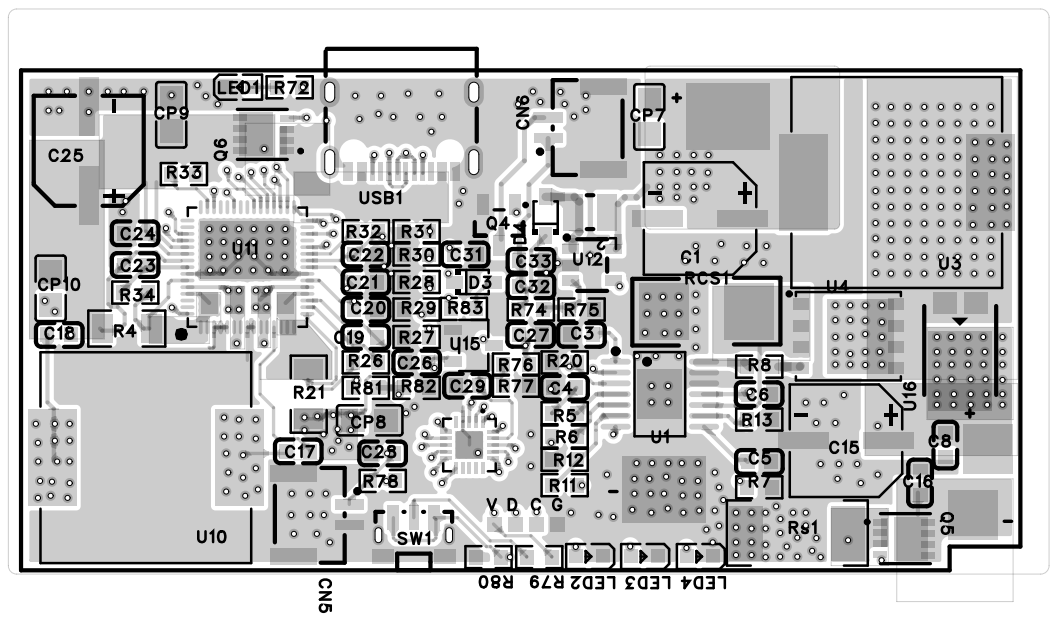
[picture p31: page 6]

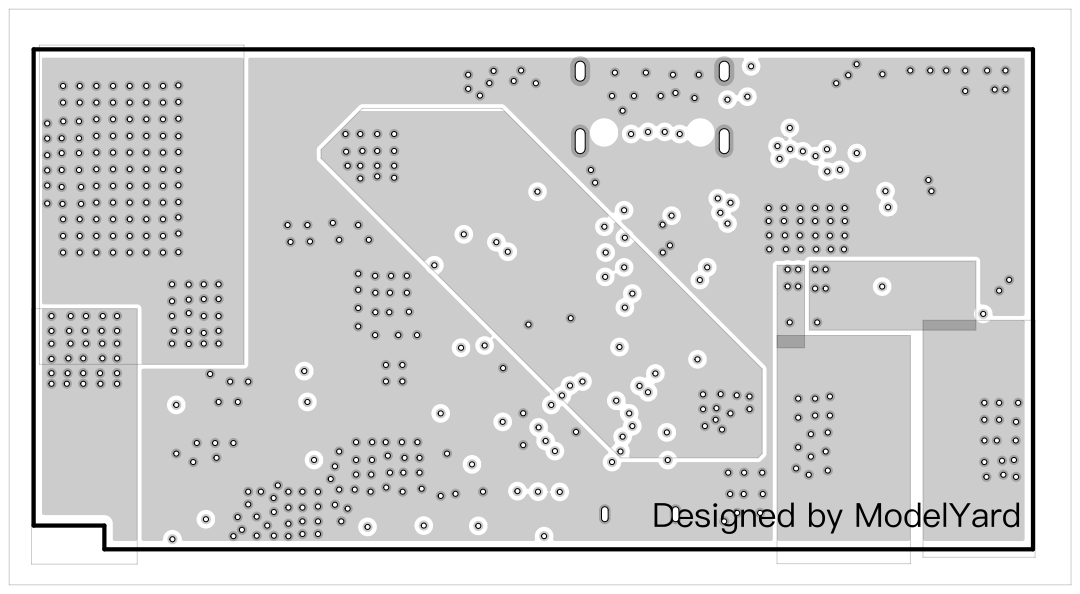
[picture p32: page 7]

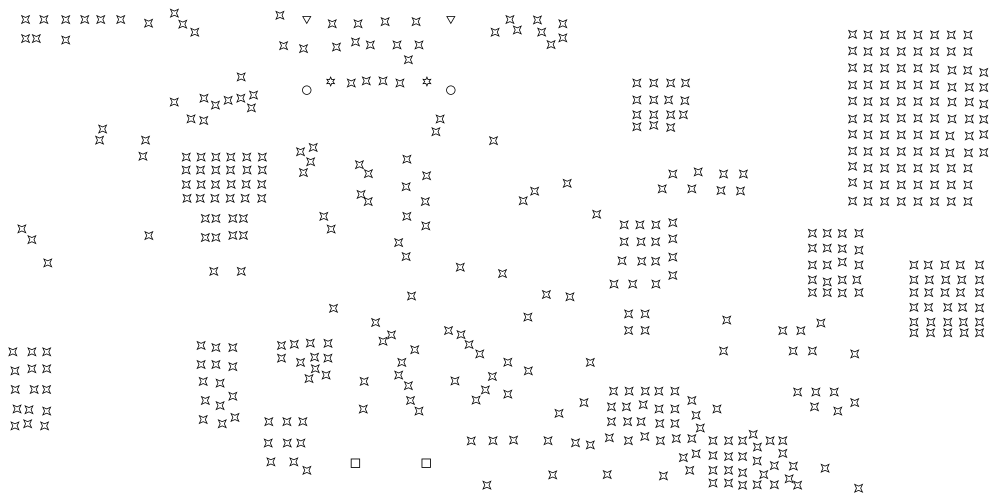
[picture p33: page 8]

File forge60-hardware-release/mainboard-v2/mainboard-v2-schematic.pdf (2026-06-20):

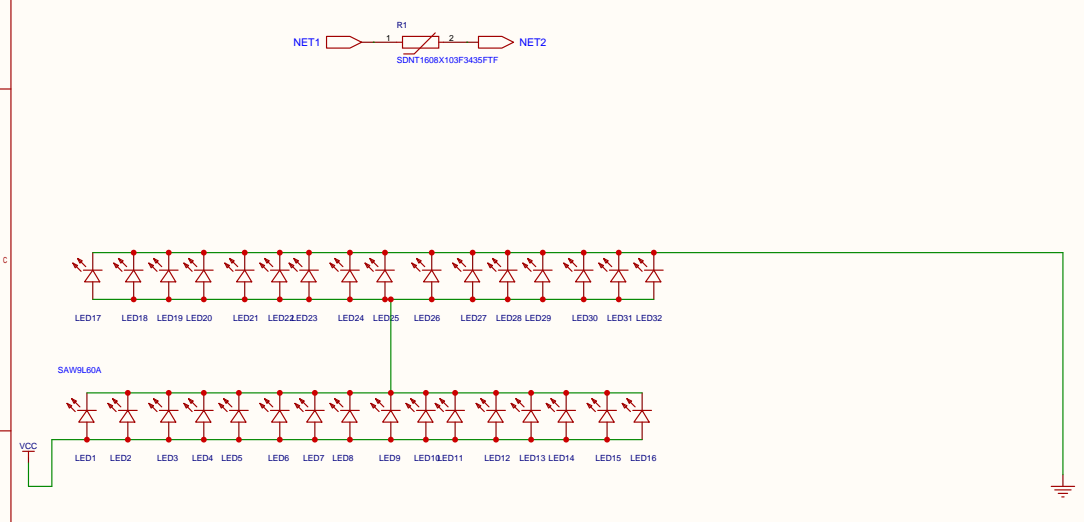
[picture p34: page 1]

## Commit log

2026-06-20 Add Forge 60 hardware release
    [led-board-5050-bom.csv, led-board-5050-bom.xlsx, led-board-5050-pick-and-place.csv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]
2026-07-06 Add Forge 60 firmware and mechanical release files
    [forge60-v10.3mf]
2026-08-09 Add Forge complete accessory package
    [500EnclosureFusion360_Source.f3z, 60Mecha_EditionHandle Extended70mm.stl, Flashlightv3 v32.f3d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]
2026-08-09 Move accessory package folders to repository root
    [500EnclosureFusion360_Source.f3z, 60Mecha_EditionHandle Extended70mm.stl, Flashlightv3 v32.f3d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]
2026-08-10 Fix Forge 60 LED board BOM part mapping
    [led-board-5050-bom.csv, led-board-5050-bom.xlsx, led-board-5050-pick-and-place.csv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]
2026-10-25 Turn the repository root into a product index and give each light its own folder.
    Forge 60 docs move into forge60/, the later products get per-product folders
    with READMEs, files are renamed consistently, duplicates are removed, and the
    swapped schematic previews are fixed. Forge OS gets its own guide. The license
    changes to CC BY-NC-SA 4.0: commercial use now requires written permission.
